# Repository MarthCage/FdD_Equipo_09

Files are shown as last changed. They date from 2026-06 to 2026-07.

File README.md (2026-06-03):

> Activar modo oscuro, por favor...

# Typing SVG (https://git.io/typing-svg)

<!-- # Equipo 09 ★ Fundamentos de Diseño ⋆｡°✩ -->
### Carrera de Ingeniería Ambiental / Informática / Industrial  
**Universidad Peruana Cayetano Heredia**

---

### <code> Descripción del Equipo ── .✦🌍 </code> 
Somos el **Equipo 09** del curso **Fundamentos de Diseño 2026-1**, conformado por estudiantes de las carreras de Ingeniería Ambiental, Informática e Industrial. Nuestro objetivo es aplicar la metodología de diseño para generar soluciones innovadoras con impacto social, tecnológico y ambiental. Somos piolas :]

---

### <code> Integrantes del Equipo ── .✦👥 </code>

<table align="center">
  <tr height="150">
    <td valign="center" width="200" align="center">
      
    </td>
    <td valign="middle">
      <b>Martha Medina˖.𖥔 ݁ ˖ ⊹ ࣪ ˖</b><br>
      Líder, documentadora y programadora<br>
      Gustos: Programación, creatividad
    </td>
    <td valign="center" width="200" align="center">
      
    </td>
    <td valign="middle">
      <b>Aldair Castillo˖.𖥔 ݁ ˖ ⊹ ࣪ ˖</b><br>
      Programador, documentador<br>
      Gustos: Ciencias de la computación, Mecatrónica
    </td>
  </tr>
  <tr height="150">
    <td valign="center" width="200" align="center">
      
    </td>
    <td valign="middle">
      <b>Anderson Bruno˖.𖥔 ݁ ˖ ⊹ ࣪ ˖</b><br>
      Documentador<br>
      Gustos: Diseño de prototipos, creatividad, análisis
    </td>
    <td valign="center" width="200" align="center">
      
    </td>
    <td valign="middle">
      <b>Angel Valverde˖.𖥔 ݁ ˖ ⊹ ࣪ ˖</b><br>
      Evaluador ambiental, documentador<br>
      Gustos: Comunicador , Asertivo , Colaborativo
    </td>
  </tr>
  <tr height="150">
    <td valign="center" width="200" align="center">
      
    </td>
    <td valign="middle">
      <b>Xiomara Quispe˖.𖥔 ݁ ˖ ⊹ ࣪ ˖</b><br>
      Documentadora<br>
      Gustos: Optimización de procesos, análisis de datos
    </td>
  </tr>
</table>

---

### <code> Fotografía del Equipo ── .✦📸 </code>

<p align="center">
imagen_alumnos_IA
  <em>Figura 1. Fotografía del equipo 09</em>
</p>

---

### <code> ODS elegida ── .✦🌍 </code> 
En este presente proyecto de innovación, se abordar una problemática vinculada al Objetivo de Desarrollo Sostenible 15 (ODS15): Vida de Ecosistema Terrestre, propuesto en la Agenda 2030. Este objetivo comprende un conjunto amplio de metas interrelacionadas que reflejan un enfoque integral orientado a la conservación de los ecosistemas terrestres y de la biodiversidad, promoviendo  soluciones que contribuyan a reducir el impacto de las actividad humana y la fauna silvestre sin alterar el equilibrio ecológico (1).

A partir de esta perspectiva, nuestro proyecto se centrará en la prevención de la pérdida de bosques ocasionada por la tala ilegal.

---

### <code> Problemática ── .✦‼️ </code> 
La deforestación se ha convertido en una de las amenazas ambientales más críticas a nivel mundial, especialmente en regiones tropicales como la Amazonía. Según reportes internacionales, más del 94% de la deforestación global ocurre en los trópicos, donde se concentran los ecosistemas más biodiversos del planeta (2).

<p align = "center">
  Captura de pantalla 2026-04-13 212824
  <br>
  <em>Tala ilegal en la Amazonía peruana (Madre de Dios).
 Nota. Tomado de Isolated Tribes and Forests Threatened by New Amazon Road, por N. Drake, 2018, National Geographic. (4)
</em>
</p>

En este contexto, el Perú no es ajeno a esta problemática. Datos de plataformas como Global Forest Watch muestran que la pérdida de cobertura arbórea en el país ha sido constante desde el año 2001, debido principalmente a actividades humanas como la agricultura, la tala y la expansión de infraestructura. Incluso, en los últimos años se han registrado incrementos significativos en la pérdida de bosques, reflejando una tendencia preocupante que continúa en aumento. Por ejemplo, en el año 2022 se registró la pérdida de aproximadamente 160 mil hectáreas de cobertura arbórea en el Perú, posicionando al país en el quinto lugar entre las naciones con mayor pérdida de bosque primario a nivel mundial con más bajas de bosque primario a nivel mundial, evidenciando así la magnitud actual del problema. Asimismo, se estima que el 67% de la pérdida de cobertura arbórea en el país está directamente asociada a procesos de deforestación, principalmente por actividades humanas como la agricultura y la tala  (2)(3).

<p align = "center">
  
  <br>
  <em>Imagen 2. Pérdida de cobertura arbórea en Perú (2001–2024). Fuente: Global Forest Watch (2024).  (3)
</em>
</p>

La importancia de esta problemática radica en sus consecuencias directas sobre el clima. La deforestación contribuye de manera significativa a las emisiones de gases de efecto invernadero, ya que los bosques almacenan grandes cantidades de carbono. Cuando estos son talados o quemados, ese carbono se libera en forma de CO₂, intensificando el calentamiento global (4). A nivel global, la pérdida de bosques tropicales está directamente relacionada con el incremento de la temperatura del planeta y eventos climáticos extremos.
Además, la Amazonía peruana alberga una enorme diversidad biológica, considerada una de las más altas del mundo. Sin embargo, la pérdida de hábitats está provocando la disminución de especies y alteraciones en los ecosistemas. La destrucción de estos ambientes también incrementa el riesgo de enfermedades zoonóticas, ya que el contacto entre humanos y animales silvestres se vuelve más frecuente (1)(4).
A nivel nacional, el problema se agrava por la ilegalidad. En el Perú, se han detectado más de 24 mil metros cúbicos de madera de origen ilegal, así como cargamentos valorizados en millones de soles, lo que evidencia la magnitud económica y ambiental de esta actividad. Un caso representativo es el ocurrido en Ucayali, donde se intervino madera ilegal valorizada en más de seis millones de soles, reflejando la alta rentabilidad de esta práctica y su impacto directo en la deforestación del país  (6)(7). Esto demuestra que la deforestación no solo es un problema ecológico, sino también social y económico.
Asimismo, la alta demanda comercial de determinadas especies forestales incrementa la presión sobre los bosques amazónicos. Entre las maderas más valoradas se encuentran la caoba (Swietenia macrophylla) y el cedro (Cedrela odorata), ampliamente utilizadas en la fabricación de muebles, acabados y productos de exportación. Debido a su elevado valor económico, estas especies han sido históricamente objeto de sobreexplotación y extracción ilegal, contribuyendo significativamente a la pérdida de cobertura forestal y al deterioro de los ecosistemas amazónicos (9).

<p align = "center">
imagen
<br>
  <em>imagen 3. Intervención de madera ilegal valorizada en más de seis millones de soles en Ucayali. Fuente: Ministerio del Interior del Perú. Ucayali: intervienen madera valorizada en más de seis millones de soles, 2023. (6)</em>
</p>

Asimismo, el modelo de desarrollo basado en la explotación de recursos ha generado una presión constante sobre los bosques amazónicos. En muchos casos, el crecimiento económico ha sido priorizado sobre la sostenibilidad, lo que ha llevado a la degradación progresiva de los ecosistemas y la pérdida de servicios ambientales esenciales como la regulación del clima y el ciclo del agua (5).
Desde una perspectiva científica, la deforestación altera procesos fundamentales como el ciclo del carbono y el equilibrio de los ecosistemas, afectando tanto a la naturaleza como a las poblaciones humanas que dependen de estos recursos para su subsistencia (8).

---

### <code> Solución ── .✦🌟 </code> 
En respuesta a la necesidad de una solución no invasiva y tras analizar la magnitud de la problemática, se propone el desarrollo de un dispositivo tecnológico innovador diseñado para detectar posibles actividades de tala ilegal en zonas vulnerables de la Amazonía. Este sistema funcionará como un mecanismo de monitoreo inteligente que integrará un micrófono para captar los sonidos del entorno y, mediante el análisis de espectros de frecuencia y técnicas de inteligencia artificial, diferenciar sonidos asociados a motosierras, maquinaria pesada, voces humanas y otros eventos relevantes.

Asimismo, el dispositivo estará basado en un microcontrolador ESP32-S3 e integrará sensores de presencia, vibración e inclinación, además de un módulo GPS para la geolocalización de eventos. Gracias a su bajo consumo energético y a la integración con una aplicación móvil, los usuarios podrán visualizar alertas, ubicación aproximada y nivel de riesgo en tiempo real. De esta manera, se busca ofrecer una solución eficiente, accesible y sostenible que contribuya a la detección temprana de actividades de tala ilegal, fortaleciendo la vigilancia forestal y apoyando la conservación de los ecosistemas amazónicos.

### <code> Objetivos ── .✦✅ </code>

- Diseñar un sistema basado en ESP32-S3 para detectar posibles casos de tala ilegal.
- Implementar un micrófono para identificar sonidos de motosierras, maquinaria y voces humanas.
- Integrar sensores de presencia y vibración para mejorar la precisión de detección.
- Enviar alertas con ubicación GPS a una aplicación móvil en tiempo real.
- Contribuir a la vigilancia y conservación de los bosques en el marco del ODS 15.

---

### <code> Patentes encontradas ── .✦📃 </code>
<!--- Patente 1 ------------------------------------------------------------------------------------------------->
<table>
  <tr>
    <th>TÍTULO</th>
    <td colspan="2"><b>SISTEMA DE DETECCIÓN DE EVENTOS SONOROS ACÚSTICOS</b></td>
  </tr>

  <tr>
    <th>NÚMERO DE PUBLICACIÓN</th>
    <td>US2025046333A1</td>
    <th>IMAGEN</th>
  </tr>

  <tr>
    <th>RESUMEN</th>
    <td>
      Esta patente describe un sistema de Machine Learning diseñado exclusivamente para clasificar "sonidos no verbales" (ruidos mecánicos, impactos, motores) extrayendo "embeddings" (vectores de características). El sistema puede aprender a reconocer una nueva clase de sonido (como un modelo específico de motosierra) usando muy pocos ejemplos de audio, sin confundirse con sonidos biológicos.
    </td>
    <td align="center">
      <br><br>
      
  </tr>

  <tr>
    <th>LINK</th>
    <td colspan="2">
      <a href="https://worldwide.espacenet.com/patent/search/family/087348851/publication/US2025046333A1?q=US20250046333A1">
        Ver patente
      </a>
    </td>
  </tr>
</table>

<br><br>

<!--- Patente 2 -------------------------------------------------------------------------------------------------->
<table>
  <tr>
    <th>TÍTULO</th>
    <td colspan="2"><b>
      Detección de tipo de audio.
    </b></td>
  </tr>

  <tr>
    <th>NÚMERO DE PUBLICACIÓN</th>
    <td>US10978050B2</td>
    <th>IMAGEN</th>
  </tr>

  <tr>
    <th>RESUMEN</th>
    <td>
      El procesamiento basado en inteligencia artificial puede utilizarse para clasificar la información de audio recibida de una unidad de entrada de audio. Por ejemplo, se puede recibir información de audio de un micrófono configurado para monitorizar un entorno. Un circuito procesador puede identificar una o más características de la información de audio recibida del micrófono y utilizar un primer algoritmo de aprendizaje automático para analizar dichas características y determinar si la información de audio incluye algún indicio de un evento anómalo en el entorno. En otro ejemplo, el circuito procesador puede utilizar un segundo algoritmo de aprendizaje automático diferente, como un algoritmo de aprendizaje profundo basado en redes neuronales, para analizar las mismas características y clasificar la información de audio como indicativa de un tipo de evento específico en el entorno 
.
    </td>
    <td align="center">
      
      <br><br>

  </tr>

  <tr>
    <th>LINK</th>
    <td colspan="2">
      <a href="https://worldwide.espacenet.com/patent/search/family/067618015/publication/US2025104698A1?q=US10978050B22">
        Ver patente
      </a>
    </td>
  </tr>
</table>

<br><br>

<!--- Patente 3 -------------------------------------------------------------------------------------------------->
<table>
  <tr>
    <th>TÍTULO</th>
    <td colspan="2"><b>
       Método, dispositivo y sistema de detección de tala ilegal basado en la diferenciación de frecuencias de audio.
    </b></td>
  </tr>

  <tr>
    <th>NÚMERO DE PUBLICACIÓN</th>
    <td>CN102393986A</td>
    <th>IMAGEN</th>
  </tr>

  <tr>
    <th>RESUMEN</th>
    <td>
 La invención proporciona un método, un dispositivo y un sistema para la detección de tala ilegal basados en la diferenciación de frecuencias de audio. Este método permite identificar actividades de tala ilegal en cualquier momento mediante la simple recolección de sonidos del entorno, presentando una baja complejidad técnica, así como costos reducidos de desarrollo y uso, además de una alta eficiencia en la detección y ejecución.
En consecuencia, el dispositivo de detección que emplea este método se caracteriza por su bajo costo de desarrollo, corto tiempo de implementación y alta eficiencia, lo que lo hace adecuado para su producción y desarrollo a nivel industrial. Asimismo, mediante la integración de este dispositivo con funciones de comunicación inalámbrica, se construye un sistema de detección de tala ilegal que permite el monitoreo remoto, la identificación de la ubicación donde ocurre la actividad ilícita y la aplicación de medidas específicas para prevenirla.
Este método, dispositivo y sistema basados en la diferenciación de frecuencias de audio logran resolver problemas presentes en tecnologías anteriores, como la dificultad en la detección de la tala ilegal y sus altos costos, mostrando además un amplio potencial de aplicación
    </td>
    <td align="center">
      
      <br><br>
      
    </td>
  </tr>

  <tr>
    <th>LINK</th>
    <td colspan="2">
      <a href="https://worldwide.espacenet.com/patent/search/family/045861294/publication/CN102393986A">
        Ver patente
      </a>
    </td>
  </tr>
</table>

<br><br>

<!--- Patente 4 -------------------------------------------------------------------------------------------------->
<table>
  <tr>
    <th>TÍTULO</th>
    <td colspan="2"><b>
        Sistema dinámico de firmas acústicas con fusión de sensores para la tala ilegal en la selva tropical
    </b></td>
  </tr>

  <tr>
    <th>NÚMERO DE PUBLICACIÓN</th>
    <td>US20240054154A1</td>
    <th>IMAGEN</th>
  </tr>

  <tr>
    <th>RESUMEN</th>
    <td>
 Las implementaciones de ejemplo descritas en este documento pueden estar dirigidas a detectar una perturbación humana a partir de datos de sensores transmitidos desde uno o más sensores dentro de una red de sensores; procesar la perturbación humana detectada para determinar una probabilidad de un evento de motosierra —por ejemplo, un evento de motosierra leve o intenso— y un tiempo estimado de anticipación para dicho evento de motosierra en un área asociada con uno o más sensores; y determinar, para los sensores vecinos de esos sensores dentro de la red, una probabilidad de cambio de estado hacia la perturbación humana o hacia el evento de motosierra en otras áreas asociadas con los sensores vecinos.
    </td>
    <td align="center">
      
      <br><br>
      
    </td>
  </tr>

  <tr>
    <th>LINK</th>
    <td colspan="2">
      <a href="https://worldwide.espacenet.com/patent/search/family/082259630/publication/US2024054154A1?q=US20240054154A1">
        Ver patente
      </a>
    </td>
  </tr>
</table>

<br><br>

---

### <code> Bibliografías ── .✦📚 </code> 
BIBLIOGRAFÍAS:
1. Moran M. ODS15: Bosques, desertificación y diversidad biológica [Internet]. Desarrollo Sostenible. 26 de enero de 2024 [citado el 14 de abril de 2026]. Disponible en: https://www.un.org/sustainabledevelopment/es/biodiversity/
2. Weisse M, Goldman E, Carter S. ¿Cuánto bosque se perdió en 2022? [Internet]. Global Forest Review; 2023 [citado 19 de abril de 2026]. Disponible en: https://gfr.wri.org/es/global-tree-cover-loss-data-2022  
3. Global Forest Watch. Peru Deforestation Rates & Statistics [Internet]. Washington, D.C.: Global Forest Watch; s. f. [citado 19 de abril de 2026]. Disponible en: https://www.globalforestwatch.org/dashboards/country/PER/ 
4. Nunez C. Why deforestation matters—and what we can do to stop it [Internet]. National Geographic; 2025 [citado 19 de abril de 2026]. Disponible en: https://www.nationalgeographic.com/environment/article/deforestation
5. Quispe Alí KE. Deforestación en la Amazonía: el costo ambiental de un desarrollo sin control [Internet]. Lima: Pontificia Universidad Católica del Perú, Clima de Cambios; 2025 [citado 19 de abril de 2026]. Disponible en: https://www.pucp.edu.pe/climadecambios/noticias/deforestacion-en-la-amazonia-el-costo-ambiental-de-un-desarrollo-sin-control/ 
6. Organismo de Supervisión de los Recursos Forestales y de Fauna Silvestre. OSINFOR identificó más de 24 mil metros cúbicos de madera de origen ilegal mediante inteligencia artificial en el monitoreo satelital [Internet]. Lima: OSINFOR; 2025 [citado 19 de abril de 2026]. Disponible en: https://www.gob.pe/institucion/osinfor/noticias/1191654-osinfor-identifico-mas-de-24-mil-metros-cubicos-de-madera-de-origen-ilegal-mediante-inteligencia-artificial-e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  
7. Ministerio del Interior. Ucayali: Intervienen madera valorizada en más de seis millones de soles [Internet]. Lima: Ministerio del Interior; 2023 [citado 19 de abril de 2026]. Disponible en: https://www.gob.pe/institucion/mininter/noticias/828157-ucayali-intervienen-madera-valorizada-en-mas-de-seis-millones-de-soles
8. La Barreda Noa SD. Deforestación en la región amazónica del Perú: situación y perspectivas. M+Rev Electrón Medioambiente [Internet]. 2021 [citado el 27 de abril de 2026];22(2):20–39. Disponible en: https://dialnet.unirioja.es/servlet/articulo?codigo=8488495 
9. Servicio Nacional Forestal y de Fauna Silvestre (SERFOR). SERFOR decomisa cargamento de caoba y cedro valorizado en 80 mil soles, Lima: SERFOR; 2024 [citado 2026 Jun 3]. Disponible en: https://www.gob.pe/institucion/serfor/noticias/1053504-serfor-decomisa-cargamento-de-caoba-y-cedro-valorizado-en-80-mil-soles

## 📌 Resumen Final  
> El proyecto aborda el impacto la tala ilegal en el Amazonas, ya que la pérdida de bosques implica un peligro para el ambiente. Como solución, se propone un dispositivo con inteligencia artificial que detecte y alarme una posible actividad de este tipo y sin dañar los alrededores, promoviendo así una solución sostenible y equilibrada con el ecosistema.

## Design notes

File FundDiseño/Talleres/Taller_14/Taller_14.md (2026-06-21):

# ACTIVIDAD 1:

No se pudo completar

# ACTIVIDAD 2: Control de ángulo de un servomotor con ESP32 mediante Bluetooth

## 1. Descripción general

En esta actividad se desarrolló un sistema para controlar el ángulo de giro de un servomotor utilizando un ESP32 y una aplicación móvil creada en MIT App Inventor.

La comunicación entre la aplicación y el ESP32 se realiza mediante Bluetooth clásico. Desde la aplicación, el usuario mueve un control deslizante o *slider*, el cual envía un valor numérico al ESP32. Luego, el ESP32 recibe ese valor, lo procesa y mueve el servomotor al ángulo correspondiente.

El sistema permite controlar el servomotor de manera inalámbrica, usando un teléfono Android como interfaz de control.

---

## 2. Código utilizado en el ESP32

```cpp
#include "BluetoothSerial.h"
#include <ESP32Servo.h>

BluetoothSerial SerialBT;
Servo servoMotor;

int pinServo = 13;
int angulo = 0;

void setup() {
  Serial.begin(115200);

  SerialBT.begin("ESP32_SERV0");
  Serial.println("Bluetooth iniciado como ESP32_SERVO");

  servoMotor.attach(pinServo);
  servoMotor.write(0);

  Serial.println("Servo listo");
}

void loop() {
  if (SerialBT.available()) {
    String dato = SerialBT.readStringUntil('\n');
    dato.trim();

    if (dato.length() > 0) {
      angulo = dato.toInt();

      if (angulo < 0) {
        angulo = 0;
      }

      if (angulo > 270) {
        angulo = 270;
      }

      int anguloServo = map(angulo, 0, 270, 0, 180);

      servoMotor.write(anguloServo);

      Serial.print("Ángulo recibido: ");
      Serial.println(angulo);
    }
  }
}
```

---

## 3. Explicación del código

### 3.1 Librerías utilizadas

Al inicio del programa se incluyen dos librerías:

```cpp
#include "BluetoothSerial.h"
#include <ESP32Servo.h>
```

La librería `BluetoothSerial.h` permite usar la comunicación Bluetooth clásica del ESP32. Gracias a esta librería, el ESP32 puede recibir datos enviados desde la aplicación móvil.

La librería `ESP32Servo.h` permite controlar el servomotor conectado al ESP32. Esta librería es necesaria porque el manejo de servomotores en ESP32 requiere una configuración diferente a la utilizada en placas como Arduino UNO.

---

### 3.2 Creación de objetos

Después se crean dos objetos principales:

```cpp
BluetoothSerial SerialBT;
Servo servoMotor;
```

El objeto `SerialBT` se utiliza para manejar la comunicación Bluetooth entre el celular y el ESP32.

El objeto `servoMotor` representa al servomotor que será controlado desde el programa.

---

### 3.3 Declaración de variables

Luego se declaran las variables principales del sistema:

```cpp
int pinServo = 13;
int angulo = 0;
```

La variable `pinServo` indica que el cable de señal del servomotor está conectado al pin GPIO 13 del ESP32.

La variable `angulo` almacena el valor recibido desde la aplicación móvil. Este valor corresponde a la posición seleccionada en el slider.

---

### 3.4 Configuración inicial del programa

La función `setup()` se ejecuta una sola vez al iniciar el ESP32. En esta parte se configuran la comunicación serial, el Bluetooth y el servomotor.

Primero se inicia la comunicación serial:

```cpp
Serial.begin(115200);
```

Esta instrucción permite mostrar mensajes en el monitor serial del Arduino IDE. Sirve para verificar si el ESP32 está funcionando correctamente y si recibe los datos enviados por Bluetooth.

Luego se inicia el Bluetooth del ESP32 con el nombre `ESP32_SERVO`:

```cpp
SerialBT.begin("ESP32_SERVO");
Serial.println("Bluetooth iniciado como ESP32_SERVO");
```

Este nombre será visible desde el celular al momento de buscar dispositivos Bluetooth. Por ello, en la aplicación móvil se debe seleccionar el dispositivo llamado `ESP32_SERVO`.

Después se configura el pin del servomotor:

```cpp
servoMotor.attach(pinServo);
servoMotor.write(0);
```

La instrucción `servoMotor.attach(pinServo)` indica que el servomotor será controlado desde el pin GPIO 13.

La instrucción `servoMotor.write(0)` coloca inicialmente el servomotor en la posición 0.

Finalmente, se muestra un mensaje indicando que el servo ya está listo:

```cpp
Serial.println("Servo listo");
```

---

### 3.5 Lectura de datos por Bluetooth

La función `loop()` se ejecuta de manera repetitiva mientras el ESP32 está encendido. Dentro de esta función se verifica constantemente si llegó algún dato por Bluetooth:

```cpp
if (SerialBT.available()) {
```

La instrucción `SerialBT.available()` comprueba si existe información disponible para leer. Si la aplicación móvil envía un valor desde el slider, esta condición se cumple.

Cuando hay información disponible, el programa lee el dato recibido:

```cpp
String dato = SerialBT.readStringUntil('\n');
dato.trim();
```

La instrucción `readStringUntil('\n')` lee el texto recibido hasta encontrar un salto de línea. Este salto de línea es enviado desde MIT App Inventor junto con el valor del slider.

La instrucción `dato.trim()` elimina espacios o caracteres innecesarios al inicio y al final del dato recibido. Esto ayuda a evitar errores al convertir el texto en número.

---

### 3.6 Validación del dato recibido

Antes de usar el dato, se verifica que no esté vacío:

```cpp
if (dato.length() > 0) {
```

Esta condición evita que el programa intente procesar un dato vacío. Si el dato tiene contenido, se convierte de texto a número entero:

```cpp
angulo = dato.toInt();
```

Esto es necesario porque los datos enviados por Bluetooth llegan como texto. Para controlar el servomotor, el valor debe convertirse a un número entero.

Por ejemplo, si la aplicación envía el texto `"90"`, el ESP32 lo convierte al número `90`.

---

### 3.7 Límite del ángulo permitido

Luego, el programa verifica que el ángulo recibido esté dentro del rango permitido:

```cpp
if (angulo < 0) {
  angulo = 0;
}

if (angulo > 270) {
  angulo = 270;
}
```

Estas condiciones evitan que el valor del ángulo sea menor que 0 o mayor que 270.

Si el valor recibido es menor que 0, el programa lo corrige a 0.

Si el valor recibido es mayor que 270, el programa lo corrige a 270.

Esto permite proteger el funcionamiento del sistema y mantener el movimiento dentro del rango definido para la actividad.

---

### 3.8 Conversión del rango del slider al rango del servo

El slider de la aplicación trabaja con valores de 0 a 270. Sin embargo, la función `servoMotor.write()` normalmente trabaja con valores de 0 a 180.

Por esa razón, se utiliza la función `map()`:

```cpp
int anguloServo = map(angulo, 0, 270, 0, 180);
```

Esta instrucción convierte proporcionalmente el valor recibido desde la aplicación.

Ejemplos:

| Valor enviado por la app | Valor usado por el servo |
|---|---|
| 0 | 0 |
| 135 | 90 |
| 270 | 180 |

De esta manera, el valor del slider se adapta al rango que puede interpretar correctamente la librería del servomotor.

---

### 3.9 Movimiento del servomotor

Después de convertir el valor, el servomotor se mueve al ángulo calculado:

```cpp
servoMotor.write(anguloServo);
```

Esta instrucción envía la señal al servomotor para que gire a la posición correspondiente.

Por ejemplo, si desde la aplicación se envía el valor 135, el programa lo convierte aproximadamente a 90, y el servomotor se mueve a esa posición.

---

### 3.10 Visualización en el monitor serial

Finalmente, el programa muestra el valor recibido en el monitor serial:

```cpp
Serial.print("Ángulo recibido: ");
Serial.println(angulo);
```

Esto permite comprobar que el ESP32 está recibiendo correctamente los datos desde la aplicación móvil.

Por ejemplo, si el usuario mueve el slider a 90, en el monitor serial se mostrará:

```text
Ángulo recibido: 90
```

Esta parte es útil para realizar pruebas y verificar que la comunicación Bluetooth funciona correctamente.

---

## 4. Funcionamiento general del sistema

El funcionamiento general del sistema es el siguiente:

1. El usuario abre la aplicación móvil creada en MIT App Inventor.
2. La aplicación se conecta al ESP32 mediante Bluetooth.
3. El usuario mueve el slider para seleccionar un ángulo.
4. La aplicación envía el valor del slider al ESP32.
5. El ESP32 recibe el dato por Bluetooth.
6. El programa convierte el dato recibido en un número entero.
7. El valor se limita entre 0 y 270.
8. El valor se convierte al rango de 0 a 180.
9. El servomotor gira a la posición correspondiente.

---

## 5. Conexión del servomotor

La conexión utilizada para el servomotor fue la siguiente:

| Cable del servomotor | Conexión en el ESP32 |
|---|---|
| Rojo | 5V |
| Marrón o negro | GND |
| Naranja o amarillo | GPIO 13 |

El cable rojo alimenta el servomotor, el cable marrón o negro se conecta a tierra y el cable naranja o amarillo recibe la señal de control desde el ESP32.

## 6. Diseño de app en MIT App Inventor:
imagen

## 7. Programación por bloques:

En esta sección se explican los bloques utilizados en MIT App Inventor para controlar el servomotor mediante Bluetooth. La aplicación permite conectarse al ESP32, enviar el valor del slider y actualizar el estado de conexión en pantalla.

Los bloques principales utilizados son:

- `Screen1.Initialize`
- `btn_connect.BeforePicking`
- `btn_connect.AfterPicking`
- `slider.PositionChanged`
- `Clock1.Timer`

--- 

imagen
imagen

---

### 7.1 Bloque `Screen1.Initialize`

El bloque `Screen1.Initialize` se ejecuta automáticamente cuando se abre la aplicación.

```text
when Screen1.Initialize
do
    set lbl_estado.Text to "Estado: Sin conectar"
    set lbl_angulo.Text to "0"
    set slider.MinValue to 0
    set slider.MaxValue to 270
    set slider.ThumbPosition to 0
```

Este bloque se encarga de establecer los valores iniciales de la aplicación.

Primero, la etiqueta `lbl_estado` muestra el mensaje:

```text
Estado: Sin conectar
```

Esto indica que al iniciar la aplicación todavía no existe conexión Bluetooth con el ESP32.

Luego, la etiqueta `lbl_angulo` muestra el valor inicial:

```text
0
```

Este valor representa la posición inicial del slider.

Después, se configura el rango del slider. El valor mínimo se establece en `0` y el valor máximo en `270`. Esto permite que el usuario seleccione un valor dentro del rango definido para la actividad.

Finalmente, la posición inicial del slider se coloca en `0`, para que al abrir la aplicación el control empiece desde el valor mínimo.

---

### 7.2 Bloque `btn_connect.BeforePicking`

El bloque `btn_connect.BeforePicking` se ejecuta antes de que el usuario seleccione un dispositivo Bluetooth.

```text
when btn_connect.BeforePicking
do
    set btn_connect.Elements to BluetoothClient1.AddressesAndNames
```

Este bloque carga en el botón de conexión la lista de dispositivos Bluetooth disponibles o previamente emparejados con el celular.

La propiedad `BluetoothClient1.AddressesAndNames` obtiene los nombres y direcciones de los dispositivos Bluetooth. Luego, esa información se asigna a los elementos del botón `btn_connect`.

Gracias a este bloque, cuando el usuario presiona el botón de conexión, la aplicación muestra una lista de dispositivos Bluetooth disponibles para conectarse.

En esta actividad, el dispositivo que debe seleccionarse es:

```text
ESP32_SERVO
```

Ese es el nombre asignado al ESP32 dentro del código cargado en Arduino IDE.

---

### 7.3 Bloque `btn_connect.AfterPicking`

El bloque `btn_connect.AfterPicking` se ejecuta después de que el usuario selecciona un dispositivo Bluetooth de la lista.

```text
when btn_connect.AfterPicking
do
    if BluetoothClient1.Connect address btn_connect.Selection
    then
        set lbl_estado.Text to "Estado: Conectado"
    else
        set lbl_estado.Text to "Estado: Error D:"
```

Este bloque intenta conectar la aplicación con el dispositivo Bluetooth seleccionado.

La instrucción:

```text
BluetoothClient1.Connect address btn_connect.Selection
```

usa el dispositivo elegido por el usuario en `btn_connect`. Si la conexión se realiza correctamente, la etiqueta `lbl_estado` cambia a:

```text
Estado: Conectado
```

Esto indica que el celular ya se encuentra conectado al ESP32.

Si la conexión falla, la aplicación muestra:

```text
Estado: Error D:
```

Este mensaje indica que no se pudo establecer la conexión Bluetooth. Esto puede suceder si el ESP32 está apagado, si no fue emparejado previamente con el celular o si se seleccionó un dispositivo incorrecto.

---

### 7.4 Bloque `slider.PositionChanged`

El bloque `slider.PositionChanged` se ejecuta cada vez que el usuario mueve el slider.

```text
when slider.PositionChanged thumbPosition
do
    set lbl_angulo.Text to round slider.ThumbPosition

    if BluetoothClient1.IsConnected
    then
        call BluetoothClient1.SendText
            text join round slider.ThumbPosition "\n"
```

Este bloque tiene dos funciones principales. La primera es mostrar en pantalla el valor actual del slider. La segunda es enviar ese valor al ESP32 mediante Bluetooth.

Primero, se actualiza la etiqueta `lbl_angulo`:

```text
set lbl_angulo.Text to round slider.ThumbPosition
```

La función `round` redondea el valor del slider para que se muestre como un número entero. Esto evita que aparezcan valores decimales en la pantalla.

Por ejemplo, si el usuario mueve el slider hacia el valor 90, la etiqueta mostrará:

```text
90
```

Luego, el bloque verifica si existe conexión Bluetooth:

```text
if BluetoothClient1.IsConnected
```

Esta condición es importante porque la aplicación solo debe enviar datos cuando está conectada al ESP32.

Si la conexión está activa, se envía el valor del slider usando:

```text
BluetoothClient1.SendText
```

El dato enviado está formado por el valor redondeado del slider unido con un salto de línea:

```text
join round slider.ThumbPosition "\n"
```

El salto de línea `\n` sirve para indicar el final del dato enviado. Esto permite que el ESP32 lea correctamente la información usando la instrucción:

```cpp
readStringUntil('\n')
```

Por ejemplo, si el usuario mueve el slider al valor 90, la aplicación envía:

```text
90\n
```

El ESP32 recibe ese dato, lo convierte a número entero y mueve el servomotor según el valor recibido.

---

### 7.5 Bloque `Clock1.Timer`

El bloque `Clock1.Timer` se ejecuta de manera repetitiva cada cierto intervalo de tiempo.

```text
when Clock1.Timer
do
    if BluetoothClient1.IsConnected
    then
        set lbl_estado.Text to "Estado: Conectado"
    else
        set lbl_estado.Text to "Estado: Sin conectar"
        set btn_connect.Text to "Conectar"
```

Este bloque sirve para verificar constantemente si la aplicación sigue conectada al ESP32.

Primero, se revisa el estado de la conexión Bluetooth mediante:

```text
BluetoothClient1.IsConnected
```

Si la conexión continúa activa, la etiqueta `lbl_estado` muestra:

```text
Estado: Conectado
```

Esto permite que el usuario sepa que la comunicación con el ESP32 sigue funcionando.

Si la conexión se pierde o todavía no se ha conectado ningún dispositivo, la etiqueta cambia a:

```text
Estado: Sin conectar
```

Además, el texto del botón vuelve a mostrarse como:

```text
Conectar
```

Esto permite que el usuario pueda intentar conectarse nuevamente.

El uso del componente `Clock1` es útil porque mantiene actualizada la interfaz de la aplicación y permite supervisar el estado de la conexión Bluetooth.

---

### 7.6 Funcionamiento general de los bloques

El funcionamiento de los bloques de la aplicación sigue el siguiente proceso:

1. Al abrir la aplicación, el bloque `Screen1.Initialize` configura los valores iniciales.
2. La aplicación muestra el estado inicial como `Estado: Sin conectar`.
3. El slider se configura con un valor mínimo de `0`, un valor máximo de `270` y una posición inicial de `0`.
4. Cuando el usuario presiona el botón de conexión, el bloque `btn_connect.BeforePicking` carga la lista de dispositivos Bluetooth disponibles.
5. El usuario selecciona el dispositivo `ESP32_SERVO`.
6. El bloque `btn_connect.AfterPicking` intenta establecer la conexión Bluetooth con el ESP32.
7. Si la conexión es correcta, la aplicación muestra `Estado: Conectado`.
8. Cuando el usuario mueve el slider, el bloque `slider.PositionChanged` muestra el valor seleccionado en la etiqueta `lbl_angulo`.
9. Si la aplicación está conectada, el valor del slider se envía al ESP32 mediante Bluetooth.
10. El bloque `Clock1.Timer` verifica constantemente si la conexión sigue activa.

---

### 7.7 Relación entre la aplicación y el ESP32

La aplicación móvil y el ESP32 trabajan juntos mediante comunicación Bluetooth.

La aplicación envía valores numéricos desde el slider. Estos valores representan el ángulo seleccionado por el usuario. El ESP32 recibe esos valores como texto, los convierte a número entero y los utiliza para mover el servomotor.

Por ejemplo:

| Acción en la aplicación | Dato enviado al ESP32 | Resultado esperado |
|---|---|---|
| Slider en 0 | `0\n` | El servo se mantiene en la posición inicial |
| Slider en 90 | `90\n` | El servo gira a una posición intermedia |
| Slider en 180 | `180\n` | El servo gira hacia una posición mayor |
| Slider en 270 | `270\n` | El servo llega al valor máximo configurado |

El salto de línea `\n` permite que el ESP32 identifique correctamente el final de cada dato recibido.

---

### 7.8 Importancia del componente `BluetoothClient`

El componente `BluetoothClient1` es el encargado de realizar la comunicación Bluetooth entre la aplicación y el ESP32.

En este proyecto, sus funciones principales son:

- Mostrar los dispositivos Bluetooth disponibles.
- Conectarse al ESP32 seleccionado.
- Verificar si la conexión está activa.
- Enviar el valor del slider al ESP32.

Sin este componente, la aplicación no podría comunicarse de forma inalámbrica con el ESP32.

---

### 7.9 Importancia del componente `Clock1`

El componente `Clock1` permite ejecutar acciones de manera repetitiva cada cierto tiempo.

En esta aplicación se utiliza para verificar si el Bluetooth sigue conectado. Gracias a esto, la aplicación puede actualizar automáticamente el mensaje de estado en la pantalla.

Esto mejora la experiencia del usuario, ya que permite saber si la aplicación está conectada o desconectada del ESP32.

---

## 7.10 Conclusión de los bloques de la aplicación

Los bloques desarrollados en MIT App Inventor permiten que la aplicación móvil funcione como una interfaz de control para el servomotor. Al iniciar la aplicación, se configuran los valores principales; luego, el usuario puede conectarse al ESP32 mediante Bluetooth y enviar el valor del slider.

El componente `BluetoothClient1` permite establecer la comunicación inalámbrica, mientras que el componente `Clock1` permite supervisar el estado de conexión. En conjunto, estos bloques permiten controlar el movimiento del servomotor desde el celular de forma sencilla y en tiempo real.

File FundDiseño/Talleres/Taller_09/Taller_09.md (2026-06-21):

# Taller 09

## Diagrama de flujo:



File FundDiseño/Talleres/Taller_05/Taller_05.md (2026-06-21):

#Pitch

En este taller se elaboró el pitch y la presentación mediante un canva

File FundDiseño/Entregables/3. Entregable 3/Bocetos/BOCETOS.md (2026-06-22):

# YURA GUARD - Bocetos

## Descripción

Bocetos del diseño del dispositivo YURA GUARD.

---

## Boceto 1: Vista Isométrica

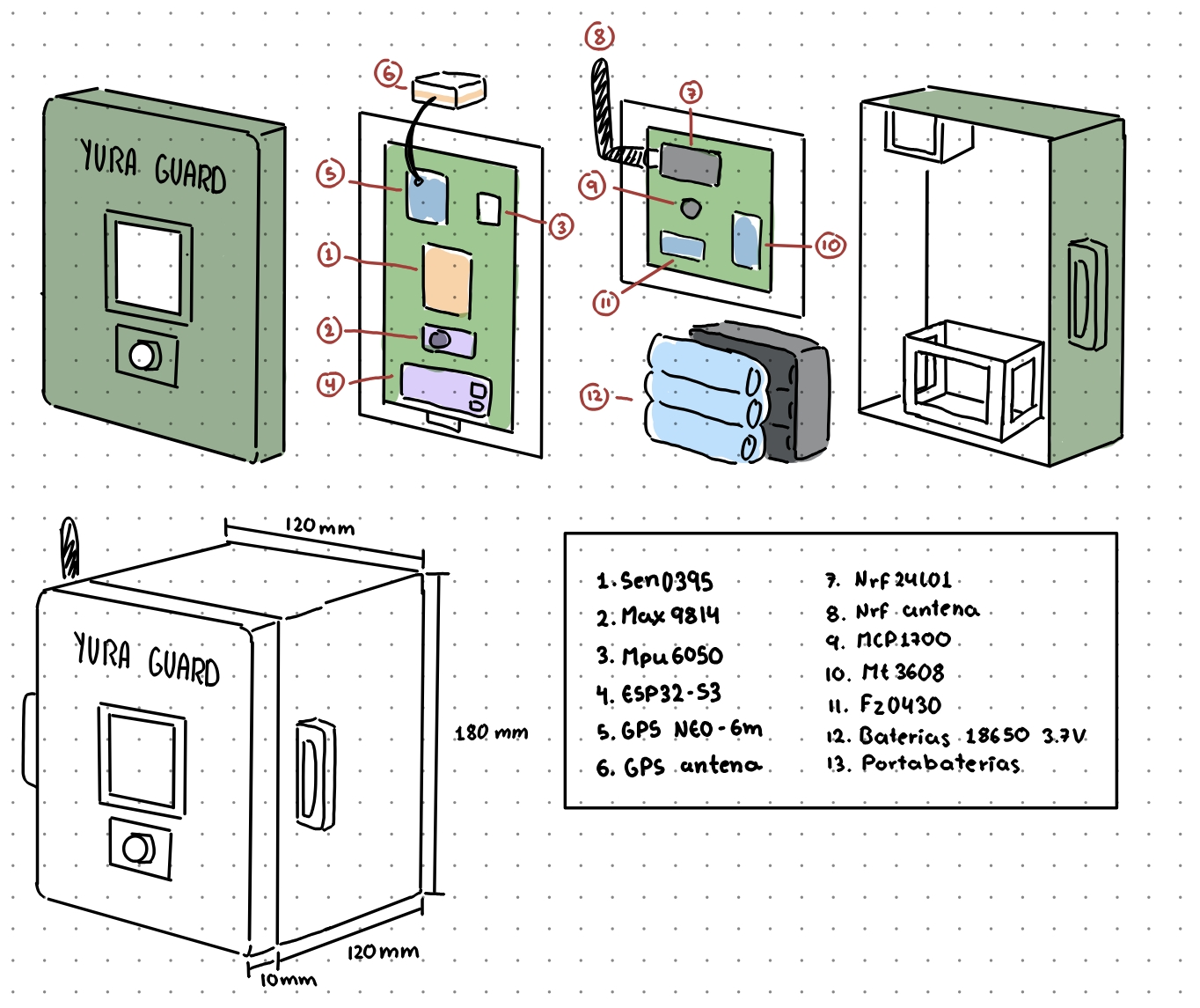
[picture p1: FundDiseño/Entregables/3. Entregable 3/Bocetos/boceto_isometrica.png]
Vista isométrica


**Descripción:** Vista tridimensional que muestra la forma general de la carcasa, la ubicación del display frontal y el asa lateral.

---

## Boceto 2: Vistas Ortogonales

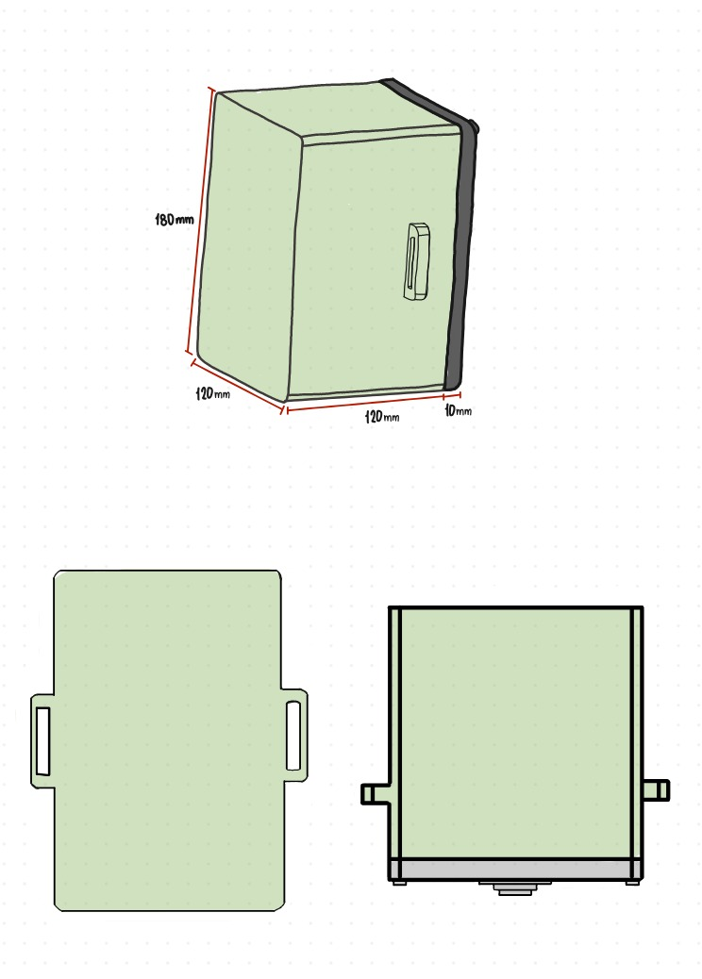
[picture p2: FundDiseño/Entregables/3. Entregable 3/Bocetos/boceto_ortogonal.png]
Vistas ortogonales


**Descripción:** Representación técnica en 2D mostrando las vistas frontal, lateral y superior.

---

## Dimensiones de ambos bocetos

- **Alto:** 180 mm
- **Ancho:** 120 mm
- **Profundidad:** 120 mm
- **Espesor de la tapa:** 10 mm

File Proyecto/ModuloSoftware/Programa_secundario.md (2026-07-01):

# Dispositivo receptor y envío de datos a la aplicación:

```
// =========================================================
// RECEPTOR / PUENTE YURAGUARD
// Recibe datos del dispositivo YuraGuard por medio del nRF24L01
// y los envía a la app por BLE en formato JSON.
// =========================================================

#include <SPI.h>
#include <RF24.h>

#include <BLEDevice.h>
#include <BLEServer.h>
#include <BLEUtils.h>
#include <BLE2902.h>

// ======================
// CONFIGURACIÓN GENERAL
// ======================
#define DEVICE_NAME "YuraGuard"

// True si se desea que la app reciba datos ni bien se inicia, false para poder usar el botón de encendido de la app jahsja (esto ya no sería necesario)
#define SISTEMA_ACTIVO_INICIAL true

// Tiempo para mostrar estado en Serial cuando no llegan paquetes
#define TIEMPO_MENSAJE_ESTADO_MS 3000UL

// Tiempo para reintentar iniciar nRF si no fue detectado
#define TIEMPO_REINTENTO_NRF_MS 5000UL

// ======================
// PINES nRF24L01
// ======================
#define NRF_CE   14
#define NRF_CSN  10
#define NRF_SCK  12
#define NRF_MOSI 11
#define NRF_MISO 13

RF24 radio(NRF_CE, NRF_CSN);
const byte address[6] = "YURA1";

bool nrfOk = false;
unsigned long ultimoReintentoNRF = 0;

// ======================
// BLE - APP INVENTOR
// UUID tipo UART BLE
// ======================
#define SERVICE_UUID        "6E400001-B5A3-F393-E0A9-E50E24DCCA9E"
#define CHARACTERISTIC_RX   "6E400002-B5A3-F393-E0A9-E50E24DCCA9E"  // App -> ESP32 negro
#define CHARACTERISTIC_TX   "6E400003-B5A3-F393-E0A9-E50E24DCCA9E"  // ESP32 negro -> App

BLEServer *bleServer = nullptr;
BLECharacteristic *txCharacteristic = nullptr;

bool appConectada = false;
bool sistemaActivo = SISTEMA_ACTIVO_INICIAL;

// Declaraciones adelantadas usadas por los callbacks BLE
void enviarEstadoBLE(const char *evento);

// ======================
// CÓDIGOS RECIBIDOS DE YURAGUARD
// ======================
#define SONIDO_BOSQUE       0
#define SONIDO_ACTIVIDAD    1   // motosierra + maquinaria agrupadas
#define SONIDO_RESERVADO    2
#define SONIDO_VOZ          3

#define PELIGRO_NORMAL      0
#define PELIGRO_TALA        1   // actividad humana / posible tala
#define PELIGRO_BATERIA     2

// ======================
// PAQUETE RECIBIDO DE YURAGUARD
// Tamaño esperado: 26 bytes.
// ======================
struct __attribute__((packed)) YuraPacket {
  uint32_t contador;

  uint8_t sonido;      // 0 bosque, 1 actividad_humana, 2 reservado, 3 voz_humana
  uint8_t presencia;   // 0 no, 1 si
  uint8_t caida;       // 0 no, 1 si
  uint8_t peligro;     // 0 normal, 1 tala/actividad, 2 bateria
  uint8_t bateria;     // 0 a 100

  float lat;
  float lng;
  float alt;
  float hdop;

  uint8_t satelites;
};

unsigned long ultimoMensajeEstado = 0;
unsigned long ultimoPaqueteMs = 0;
YuraPacket ultimoPaquete;
bool hayPaqueteValido = false;

// ======================
// BLE CALLBACKS
// ======================
class ServerCallbacks : public BLEServerCallbacks {
  void onConnect(BLEServer *pServer) override {
    appConectada = true;
    Serial.println("BLE: app conectada.");
  }

  void onDisconnect(BLEServer *pServer) override {
    appConectada = false;
    Serial.println("BLE: app desconectada. Reiniciando advertising...");
    delay(100);
    pServer->startAdvertising();
  }
};

class RXCallbacks : public BLECharacteristicCallbacks {
  void onWrite(BLECharacteristic *pCharacteristic) override {
    String comando = String(pCharacteristic->getValue().c_str());
    comando.trim();
    comando.toUpperCase();

    Serial.print("BLE comando recibido: ");
    Serial.println(comando);

    if (comando == "ON" || comando == "1" || comando == "START") {
      sistemaActivo = true;
      Serial.println("Sistema activado desde app.");
      enviarEstadoBLE("sistema_activado");
    }
    else if (comando == "OFF" || comando == "0" || comando == "STOP") {
      sistemaActivo = false;
      Serial.println("Sistema apagado desde app.");
      enviarEstadoBLE("sistema_apagado");
    }
    else if (comando == "PING" || comando == "ESTADO") {
      enviarEstadoBLE("estado");
    }
    else {
      Serial.println("Comando no reconocido. Usa ON, OFF, PING o ESTADO.");
      enviarEstadoBLE("comando_no_reconocido");
    }
  }
};

// ======================
// CONVERSIÓN A TEXTO
// ======================
const char* textoSonido(uint8_t sonido) {
  switch (sonido) {
    case SONIDO_BOSQUE:
      return "bosque";
    case SONIDO_ACTIVIDAD:
      return "actividad_humana";   // motosierra + maquinaria agrupadas
    case SONIDO_RESERVADO:
      return "reservado";
    case SONIDO_VOZ:
      return "voz_humana";
    default:
      return "desconocido";
  }
}

const char* textoSiNo(uint8_t valor) {
  return valor ? "si" : "no";
}

const char* textoPeligro(uint8_t peligro) {
  switch (peligro) {
    case PELIGRO_NORMAL:
      return "normal";
    case PELIGRO_TALA:
      return "tala";
    case PELIGRO_BATERIA:
      return "bateria";
    default:
      return "desconocido";
  }
}

// ======================
// CREAR JSON PARA APP INVENTOR
// Mantiene las claves antiguas y agrega contador, satelites, hdop y activo.
// ======================
String crearJSON(const YuraPacket &data) {
  String json;
  json.reserve(220);

  json += "{";
  json += "\"contador\":" + String(data.contador) + ",";
  json += "\"sonido\":\"" + String(textoSonido(data.sonido)) + "\",";
  json += "\"presencia\":\"" + String(textoSiNo(data.presencia)) + "\",";
  json += "\"caida\":\"" + String(textoSiNo(data.caida)) + "\",";
  json += "\"peligro\":\"" + String(textoPeligro(data.peligro)) + "\",";
  json += "\"bateria\":" + String(data.bateria) + ",";
  json += "\"lat\":" + String(data.lat, 6) + ",";
  json += "\"lon\":" + String(data.lng, 6) + ",";
  json += "\"alt\":" + String(data.alt, 1) + ",";
  json += "\"satelites\":" + String(data.satelites) + ",";
  json += "\"hdop\":" + String(data.hdop, 2) + ",";
  json += "\"activo\":\"" + String(sistemaActivo ? "si" : "no") + "\"";
  json += "}";

  return json;
}

String crearJSONEstado(const char *evento) {
  String json;
  json.reserve(120);

  json += "{";
  json += "\"evento\":\"" + String(evento) + "\",";
  json += "\"ble\":\"" + String(appConectada ? "conectado" : "desconectado") + "\",";
  json += "\"sistema\":\"" + String(sistemaActivo ? "activo" : "apagado") + "\",";
  json += "\"nrf\":\"" + String(nrfOk ? "ok" : "no_detectado") + "\",";
  json += "\"hay_datos\":\"" + String(hayPaqueteValido ? "si" : "no") + "\"";
  json += "}";

  return json;
}

// ======================
// ENVIAR A LA APP POR BLE
// ======================
void enviarBLE(const String &json, bool forzarEnvio = false) {
  if (!appConectada) {
    Serial.println("BLE: no se envia, app no conectada.");
    return;
  }

  if (!sistemaActivo && !forzarEnvio) {
    Serial.println("BLE: no se envia paquete, sistema apagado.");
    return;
  }

  if (txCharacteristic == nullptr) {
    Serial.println("BLE: TX characteristic no inicializada.");
    return;
  }

  txCharacteristic->setValue(json.c_str());
  txCharacteristic->notify();

  Serial.print("BLE JSON enviado: ");
  Serial.println(json);
}

void enviarEstadoBLE(const char *evento) {
  String json = crearJSONEstado(evento);
  enviarBLE(json, true);
}

// ======================
// IMPRIMIR PAQUETE EN SERIAL
// ======================
void imprimirPaquete(const YuraPacket &data) {
  Serial.println("========== PAQUETE RECIBIDO ==========");

  Serial.print("Contador: ");
  Serial.println(data.contador);

  Serial.print("Sonido: ");
  Serial.println(textoSonido(data.sonido));

  Serial.print("Presencia: ");
  Serial.println(textoSiNo(data.presencia));

  Serial.print("Caida: ");
  Serial.println(textoSiNo(data.caida));

  Serial.print("Peligro: ");
  Serial.println(textoPeligro(data.peligro));

  Serial.print("Bateria: ");
  Serial.print(data.bateria);
  Serial.println("%");

  Serial.print("Latitud: ");
  Serial.println(data.lat, 6);

  Serial.print("Longitud: ");
  Serial.println(data.lng, 6);

  Serial.print("Altitud: ");
  Serial.println(data.alt, 1);

  Serial.print("Satelites: ");
  Serial.println(data.satelites);

  Serial.print("HDOP: ");
  Serial.println(data.hdop, 2);
}

// ======================
// INICIAR NRF24L01
// No bloquea el programa si falla.
// ======================
bool iniciarNRF() {
  SPI.begin(NRF_SCK, NRF_MISO, NRF_MOSI, NRF_CSN);

  if (!radio.begin()) {
    Serial.println("ERROR: NRF24L01 no detectado en receptor negro.");
    Serial.println("Revisa VCC 3.3V, GND, CE, CSN, SCK, MOSI y MISO.");
    nrfOk = false;
    return false;
  }

  radio.setChannel(90);
  radio.setDataRate(RF24_250KBPS);
  radio.setPALevel(RF24_PA_LOW);

  radio.setAutoAck(true);
  radio.setRetries(5, 15);
  radio.setPayloadSize(sizeof(YuraPacket));

  radio.openReadingPipe(1, address);
  radio.startListening();
  radio.flush_rx();

  nrfOk = true;

  Serial.println("NRF24L01 receptor detectado.");
  Serial.print("Tamano paquete receptor: ");
  Serial.print(sizeof(YuraPacket));
  Serial.println(" bytes");

  if (sizeof(YuraPacket) <= 32) {
    Serial.println("Paquete compatible con nRF24L01.");
  } else {
    Serial.println("ERROR: paquete mayor a 32 bytes. nRF24L01 no puede enviarlo.");
  }

  Serial.println("Receptor nRF listo.");
  return true;
}

void reintentarNRFSiHaceFalta() {
  if (nrfOk) return;

  if (millis() - ultimoReintentoNRF >= TIEMPO_REINTENTO_NRF_MS) {
    ultimoReintentoNRF = millis();
    Serial.println("Reintentando iniciar nRF24L01...");
    iniciarNRF();
  }
}

// ======================
// INICIAR BLE
// ======================
void iniciarBLE() {
  BLEDevice::init(DEVICE_NAME);
  BLEDevice::setMTU(185);

  bleServer = BLEDevice::createServer();
  bleServer->setCallbacks(new ServerCallbacks());

  BLEService *service = bleServer->createService(SERVICE_UUID);

  txCharacteristic = service->createCharacteristic(
    CHARACTERISTIC_TX,
    BLECharacteristic::PROPERTY_NOTIFY
  );
  txCharacteristic->addDescriptor(new BLE2902());

  BLECharacteristic *rxCharacteristic = service->createCharacteristic(
    CHARACTERISTIC_RX,
    BLECharacteristic::PROPERTY_WRITE
  );
  rxCharacteristic->setCallbacks(new RXCallbacks());

  service->start();

  BLEAdvertising *advertising = BLEDevice::getAdvertising();
  advertising->addServiceUUID(SERVICE_UUID);
  advertising->setScanResponse(true);
  advertising->setMinPreferred(0x06);
  advertising->setMinPreferred(0x12);

  BLEDevice::startAdvertising();

  Serial.print("BLE listo. Busca el dispositivo: ");
  Serial.println(DEVICE_NAME);
}

// ======================
// LEER PAQUETE NRF
// ======================
bool leerPaqueteNRF(YuraPacket &data) {
  if (!nrfOk) return false;
  if (!radio.available()) return false;

  // Si llegaron varios paquetes, nos quedamos con el último.
  while (radio.available()) {
    radio.read(&data, sizeof(data));
  }

  return true;
}

// ======================
// MENSAJE DE ESTADO SERIAL
// ======================
void imprimirEstadoPeriodico() {
  if (millis() - ultimoMensajeEstado < TIEMPO_MENSAJE_ESTADO_MS) return;
  ultimoMensajeEstado = millis();

  Serial.println("---------- ESTADO RECEPTOR ----------");
  Serial.print("nRF: ");
  Serial.println(nrfOk ? "OK" : "NO DETECTADO");

  Serial.print("BLE conectado: ");
  Serial.println(appConectada ? "SI" : "NO");

  Serial.print("Sistema activo: ");
  Serial.println(sistemaActivo ? "SI" : "NO");

  Serial.print("Hay paquete recibido: ");
  Serial.println(hayPaqueteValido ? "SI" : "NO");

  if (hayPaqueteValido) {
    Serial.print("Ultimo paquete hace: ");
    Serial.print((millis() - ultimoPaqueteMs) / 1000.0, 1);
    Serial.println(" s");
  } else {
    Serial.println("Esperando paquetes del ESP32 morado...");
  }

  Serial.println("--------------------------------------");
  Serial.println();
}

// ======================
// SETUP
// ======================
void setup() {
  Serial.begin(115200);
  delay(1500);

  Serial.println();
  Serial.println("========================================");
  Serial.println("ESP32 NEGRO - RECEPTOR PUENTE YURAGUARD");
  Serial.println("========================================");

  Serial.print("Sistema activo inicial: ");
  Serial.println(sistemaActivo ? "SI" : "NO");

  iniciarNRF();
  iniciarBLE();

  Serial.println("Listo. Esperando paquetes del ESP32 morado...");
  Serial.println();
}

// ======================
// LOOP
// ======================
void loop() {
  reintentarNRFSiHaceFalta();

  YuraPacket data;

  if (leerPaqueteNRF(data)) {
    ultimoPaquete = data;
    hayPaqueteValido = true;
    ultimoPaqueteMs = millis();

    imprimirPaquete(data);

    String json = crearJSON(data);

    Serial.print("JSON creado: ");
    Serial.println(json);

    enviarBLE(json);

    Serial.println("======================================");
    Serial.println();
  }

  imprimirEstadoPeriodico();
}

```

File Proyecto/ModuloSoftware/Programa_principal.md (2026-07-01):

# Dispositivo YuraGuard

```
/* =========================================================
   YURAGUARD
   Envia el paquete con el siguiente contenido:

   contador, sonido, presencia, caida, peligro, bateria,
   lat, lng, alt, hdop, satelites

   IA Edge Impulse:
   - bosque = normal
   - voz_humana + actividad_humana = alerta
   - actividad_humana representa motosierra + maquinaria
   ========================================================= */

#define EIDSP_QUANTIZE_FILTERBANK 0
#include <MarthCage-project-1_inferencing.h>

#include <Arduino.h>
#include <Wire.h>
#include <TinyGPSPlus.h>
#include <Adafruit_MPU6050.h>
#include <Adafruit_Sensor.h>
#include <SPI.h>
#include <RF24.h>
#include <math.h>
#include <string.h>

// ======================
// PINES
// ======================
#define MIC_PIN 4

#define PIN_GPS_RX_ESP 10
#define PIN_GPS_TX_ESP 9

#define PIN_RADAR_RX_ESP 16
#define PIN_RADAR_TX_ESP 18

#define PIN_MPU_SDA 21
#define PIN_MPU_SCL 20

#define NRF_CE   35
#define NRF_CSN  36
#define NRF_SCK  37
#define NRF_MOSI 38
#define NRF_MISO 39

// Bateria FZ0430: S/OUT -> GPIO1
#define PIN_BATERIA 1

// Calibrado con pack real 3.54 V y lectura ADC aprox. 0.629 V
#define FACTOR_FZ0430 5.63f

// Escala de porcentaje para prototipo
#define VOLTAJE_BATERIA_MIN 3.30f
#define VOLTAJE_BATERIA_MAX 3.70f

// Cambia a 0 para probar sin FZ0430/bateria
#define USAR_SENSOR_BATERIA 1

// ======================
// AJUSTES
// ======================
#define AUDIO_GAIN 2
#define RMS_ALERTA_MIN 120
// Deteccion mejorada de caida con MPU6050
// Fase 1: caida libre si la magnitud baja de 0.55G
// Fase 2: impacto si luego sube sobre 2.0G en menos de 1 segundo
#define CAIDA_LIBRE_G_MAX 0.55f
#define CAIDA_IMPACTO_G_MIN 2.00f
#define CAIDA_TIEMPO_MAX_MS 1000UL

// La caida detectada queda pendiente hasta que se envie el siguiente paquete NRF

// Si quieres que sonido de alerta necesite presencia radar, pon 1
#define EXIGIR_PRESENCIA_PARA_TALA 0

// ======================
// CODIGOS DEL PAQUETE
// Deben coincidir con el ESP32 negro
// ======================
#define SONIDO_BOSQUE       0
#define SONIDO_ACTIVIDAD    1   // motosierra + maquinaria agrupadas
#define SONIDO_RESERVADO    2
#define SONIDO_VOZ          3

#define PELIGRO_NORMAL      0
#define PELIGRO_TALA        1
#define PELIGRO_BATERIA     2

// ======================
// OBJETOS
// ======================
HardwareSerial GPSSerial(2);
HardwareSerial RadarSerial(1);
TinyGPSPlus gps;
Adafruit_MPU6050 mpu;

RF24 radio(NRF_CE, NRF_CSN);
const byte address[6] = "YURA1";

// ======================
// PAQUETE NRF
// IMPORTANTE: igual al struct del ESP32 negro
// Tamaño esperado: 26 bytes
// ======================
struct __attribute__((packed)) YuraPacket {
  uint32_t contador;

  uint8_t sonido;
  uint8_t presencia;
  uint8_t caida;
  uint8_t peligro;
  uint8_t bateria;

  float lat;
  float lng;
  float alt;
  float hdop;

  uint8_t satelites;
};

// ======================
// EDGE IMPULSE AUDIO
// ======================
typedef struct {
  signed short *buffers[2];
  unsigned char buf_select;
  volatile unsigned char buf_ready;
  unsigned int buf_count;
  unsigned int n_samples;
} inference_t;

static inference_t inference;
static bool debug_nn = false;
static int print_results = -(EI_CLASSIFIER_SLICES_PER_MODEL_WINDOW);
static bool record_status = true;
static int adc_center = 1430;

volatile int32_t audio_peak = 0;
volatile float audio_rms = 0.0f;
volatile bool pausarAudioADC = false;

// Estado compartido de caida mejorada
volatile bool caidaPendiente = false;
volatile bool posibleCaidaLibre = false;
volatile unsigned long tiempoCaidaLibre = 0;
volatile float ultimaVibracionMPU = 0.0f;
volatile float ultimaGMPU = 1.0f;

// ======================
// ESTADO
// ======================
bool mpuOk = false;
bool nrfOk = false;
bool iaOk = false;
uint32_t contador = 0;

// ======================
// PROTOTIPOS
// ======================
void feedGPS();
void calibrar_microfono();
bool microphone_inference_start(uint32_t n_samples);
bool microphone_inference_record();
int microphone_audio_signal_get_data(size_t offset, size_t length, float *out_ptr);
void microphone_inference_end();
void capture_samples(void* arg);
void tareaCaidaMPU(void* arg);

void inicializarSensores();
void inicializarNRF();
void inicializarIA();

uint8_t clasificarSonido(const ei_impulse_result_t &result);
uint8_t leerPresenciaRadar();
uint8_t leerCaidaMPU(float *vibracionOut);
uint8_t leerBateria();
uint8_t analizarPeligro(uint8_t sonido, uint8_t presencia, uint8_t caida, uint8_t bateria);
void crearYEnviarPaquete(uint8_t sonido);
void imprimirPaquete(const YuraPacket &data);

String textoSonido(uint8_t sonido);
String textoSiNo(uint8_t v);
String textoPeligro(uint8_t peligro);

// ======================
// SETUP
// ======================
void setup() {
  Serial.begin(115200);
  delay(1500);

  Serial.println();
  Serial.println("INICIANDO YURAGUARD MORADO - ENVIO MINIMO");

  inicializarSensores();
  inicializarNRF();
  inicializarIA();

  Serial.print("Tamano YuraPacket: ");
  Serial.print(sizeof(YuraPacket));
  Serial.println(" bytes");
  Serial.println("Sistema listo.");
  Serial.println();
}

// ======================
// LOOP
// ======================
void loop() {
  feedGPS();

  if (!iaOk) {
    delay(500);
    return;
  }

  if (!microphone_inference_record()) {
    Serial.println("ERR: fallo al grabar audio");
    return;
  }

  signal_t signal;
  signal.total_length = EI_CLASSIFIER_SLICE_SIZE;
  signal.get_data = &microphone_audio_signal_get_data;

  ei_impulse_result_t result = {0};
  EI_IMPULSE_ERROR r = run_classifier_continuous(&signal, &result, debug_nn);

  if (r != EI_IMPULSE_OK) {
    Serial.print("ERR: clasificador fallo: ");
    Serial.println((int)r);
    return;
  }

  // Solo enviamos cuando ya hay una ventana completa de IA
  if (++print_results >= EI_CLASSIFIER_SLICES_PER_MODEL_WINDOW) {
    uint8_t sonido = clasificarSonido(result);
    crearYEnviarPaquete(sonido);
    print_results = 0;
  }
}

// ======================
// INICIALIZACION
// ======================
void inicializarSensores() {
  analogReadResolution(12);
  analogSetPinAttenuation(MIC_PIN, ADC_11db);
  pinMode(PIN_BATERIA, INPUT);
  analogSetPinAttenuation(PIN_BATERIA, ADC_11db);

  GPSSerial.begin(9600, SERIAL_8N1, PIN_GPS_RX_ESP, PIN_GPS_TX_ESP);
  RadarSerial.begin(115200, SERIAL_8N1, PIN_RADAR_RX_ESP, PIN_RADAR_TX_ESP);

  Wire.begin(PIN_MPU_SDA, PIN_MPU_SCL);
  Wire.setClock(400000);

  mpuOk = mpu.begin(0x68, &Wire);
  if (mpuOk) {
    mpu.setAccelerometerRange(MPU6050_RANGE_8_G);
    mpu.setGyroRange(MPU6050_RANGE_500_DEG);
    mpu.setFilterBandwidth(MPU6050_BAND_21_HZ);
    Serial.println("MPU6050 OK");

    BaseType_t tareaOk = xTaskCreatePinnedToCore(
      tareaCaidaMPU,
      "TareaCaidaMPU",
      4096,
      NULL,
      1,
      NULL,
      1
    );

    if (tareaOk == pdPASS) {
      Serial.println("Deteccion mejorada de caida OK");
    } else {
      Serial.println("ERR: no se pudo iniciar tarea de caida");
    }
  } else {
    Serial.println("MPU6050 no detectado");
  }
}

void inicializarNRF() {
  SPI.begin(NRF_SCK, NRF_MISO, NRF_MOSI, NRF_CSN);

  nrfOk = radio.begin();
  if (!nrfOk) {
    Serial.println("NRF24L01 no detectado");
    return;
  }

  radio.setChannel(90);
  radio.setDataRate(RF24_250KBPS);
  radio.setPALevel(RF24_PA_LOW);
  radio.setAutoAck(true);
  radio.setRetries(5, 15);
  radio.setPayloadSize(sizeof(YuraPacket));
  radio.openWritingPipe(address);
  radio.stopListening();

  Serial.println("NRF24L01 OK");
}

void inicializarIA() {
  Serial.println("Calibrando microfono...");
  calibrar_microfono();

  Serial.print("ADC center: ");
  Serial.println(adc_center);

  run_classifier_init();

  if (!microphone_inference_start(EI_CLASSIFIER_SLICE_SIZE)) {
    Serial.println("ERR: no se pudo iniciar buffer de audio");
    iaOk = false;
    return;
  }

  iaOk = true;
  Serial.println("IA OK");
}

// ======================
// GPS
// ======================
void feedGPS() {
  while (GPSSerial.available()) {
    gps.encode(GPSSerial.read());
  }
}

// ======================
// CLASIFICACION IA
// ======================
uint8_t clasificarSonido(const ei_impulse_result_t &result) {
  float p_bosque = 0.0f;
  float p_voz = 0.0f;
  float p_actividad = 0.0f;

  for (size_t ix = 0; ix < EI_CLASSIFIER_LABEL_COUNT; ix++) {
    const char *label = result.classification[ix].label;
    float value = result.classification[ix].value;

    if (strcmp(label, "bosque") == 0 || strcmp(label, "BOSQUE") == 0) {
      p_bosque = value;
    }
    else if (
      strcmp(label, "voz_humana") == 0 ||
      strcmp(label, "voz humana") == 0 ||
      strcmp(label, "VOZ_HUMANA") == 0 ||
      strcmp(label, "VOZ HUMANA") == 0
    ) {
      p_voz = value;
    }
    else if (
      strcmp(label, "actividad_humana") == 0 ||
      strcmp(label, "actividad humana") == 0 ||
      strcmp(label, "ACTIVIDAD_HUMANA") == 0 ||
      strcmp(label, "ACTIVIDAD HUMANA") == 0
    ) {
      p_actividad = value;
    }
  }

  float p_alerta = p_voz + p_actividad;

  if (audio_peak >= 32000) {
    // Audio saturado: se conserva el resultado, pero seria bueno bajar AUDIO_GAIN.
  }

  if (p_alerta > p_bosque && audio_rms > RMS_ALERTA_MIN) {
    if (p_voz >= p_actividad) {
      return SONIDO_VOZ;
    }
    return SONIDO_ACTIVIDAD;
  }

  return SONIDO_BOSQUE;
}

// ======================
// SENSORES
// ======================
uint8_t leerPresenciaRadar() {
  uint8_t presencia = 0;

  if (RadarSerial.available()) {
    presencia = 1;
    while (RadarSerial.available()) {
      RadarSerial.read();
    }
  }

  return presencia;
}

void tareaCaidaMPU(void* arg) {
  (void)arg;

  while (true) {
    if (!mpuOk) {
      vTaskDelay(pdMS_TO_TICKS(200));
      continue;
    }

    sensors_event_t acc, gyro, temp;
    mpu.getEvent(&acc, &gyro, &temp);

    float accMag = sqrt(
      acc.acceleration.x * acc.acceleration.x +
      acc.acceleration.y * acc.acceleration.y +
      acc.acceleration.z * acc.acceleration.z
    );

    float gActual = accMag / 9.81f;
    float vibracion = fabs(accMag - 9.81f);
    unsigned long ahora = millis();

    ultimaGMPU = gActual;
    ultimaVibracionMPU = vibracion;

    // Fase 1: posible caida libre.
    if (!posibleCaidaLibre && gActual < CAIDA_LIBRE_G_MAX) {
      posibleCaidaLibre = true;
      tiempoCaidaLibre = ahora;
    }

    // Fase 2: impacto fuerte despues de la caida libre.
    if (posibleCaidaLibre &&
        gActual > CAIDA_IMPACTO_G_MIN &&
        (ahora - tiempoCaidaLibre) <= CAIDA_TIEMPO_MAX_MS) {
      caidaPendiente = true;
      posibleCaidaLibre = false;
    }

    // Si no hubo impacto a tiempo, se cancela la posible caida.
    if (posibleCaidaLibre &&
        (ahora - tiempoCaidaLibre) > CAIDA_TIEMPO_MAX_MS) {
      posibleCaidaLibre = false;
    }

    vTaskDelay(pdMS_TO_TICKS(20));
  }
}

uint8_t leerCaidaMPU(float *vibracionOut) {
  if (!mpuOk) {
    *vibracionOut = 0.0f;
    return 0;
  }

  *vibracionOut = ultimaVibracionMPU;

  // Se consume la caida pendiente para enviarla una sola vez por NRF.
  if (caidaPendiente) {
    caidaPendiente = false;
    return 1;
  }

  return 0;
}

uint8_t leerBateria() {
#if USAR_SENSOR_BATERIA == 0
  return 100;
#else
  // Pausa temporal de audio para evitar conflicto ADC con el MAX9814.
  pausarAudioADC = true;
  delay(30);

  analogSetPinAttenuation(PIN_BATERIA, ADC_11db);

  for (int i = 0; i < 10; i++) {
    analogRead(PIN_BATERIA);
    delay(2);
  }

  const int muestras = 25;
  int lecturas[muestras];

  for (int i = 0; i < muestras; i++) {
    lecturas[i] = analogRead(PIN_BATERIA);
    delay(4);
  }

  analogSetPinAttenuation(MIC_PIN, ADC_11db);
  pausarAudioADC = false;

  // Ordenar para mediana
  for (int i = 0; i < muestras - 1; i++) {
    for (int j = i + 1; j < muestras; j++) {
      if (lecturas[j] < lecturas[i]) {
        int tmp = lecturas[i];
        lecturas[i] = lecturas[j];
        lecturas[j] = tmp;
      }
    }
  }

  int lecturaMediana = lecturas[muestras / 2];
  float voltajeADC = (lecturaMediana / 4095.0f) * 3.3f;
  float voltajeBateria = voltajeADC * FACTOR_FZ0430;

  if (lecturaMediana < 20) {
    return 0;
  }

  float porcentaje = ((voltajeBateria - VOLTAJE_BATERIA_MIN) /
                     (VOLTAJE_BATERIA_MAX - VOLTAJE_BATERIA_MIN)) * 100.0f;

  if (porcentaje > 100.0f) porcentaje = 100.0f;
  if (porcentaje < 0.0f) porcentaje = 0.0f;

  return (uint8_t)porcentaje;
#endif
}

uint8_t analizarPeligro(uint8_t sonido, uint8_t presencia, uint8_t caida, uint8_t bateria) {
  bool sonidoAlerta = (sonido == SONIDO_ACTIVIDAD || sonido == SONIDO_VOZ);

#if EXIGIR_PRESENCIA_PARA_TALA == 1
  if (sonidoAlerta && presencia == 1) {
    return PELIGRO_TALA;
  }
#else
  if (sonidoAlerta) {
    return PELIGRO_TALA;
  }
#endif

  if (bateria <= 20) {
    return PELIGRO_BATERIA;
  }

  return PELIGRO_NORMAL;
}

// ======================
// CREAR Y ENVIAR PAQUETE
// ======================
void crearYEnviarPaquete(uint8_t sonido) {
  feedGPS();

  float vibracion = 0.0f;
  uint8_t caida = leerCaidaMPU(&vibracion);
  uint8_t presencia = leerPresenciaRadar();
  uint8_t bateria = leerBateria();

  float lat = 0.0f;
  float lng = 0.0f;
  float alt = 0.0f;
  float hdop = 99.99f;
  uint8_t satelites = 0;

  if (gps.location.isValid()) {
    lat = gps.location.lat();
    lng = gps.location.lng();
  }

  if (gps.altitude.isValid()) {
    alt = gps.altitude.meters();
  }

  if (gps.hdop.isValid()) {
    hdop = gps.hdop.hdop();
  }

  if (gps.satellites.isValid()) {
    satelites = gps.satellites.value();
  }

  uint8_t peligro = analizarPeligro(sonido, presencia, caida, bateria);

  YuraPacket data;
  data.contador = contador++;
  data.sonido = sonido;
  data.presencia = presencia;
  data.caida = caida;
  data.peligro = peligro;
  data.bateria = bateria;
  data.lat = lat;
  data.lng = lng;
  data.alt = alt;
  data.hdop = hdop;
  data.satelites = satelites;

  if (nrfOk) {
    bool enviado = radio.write(&data, sizeof(data));
    if (!enviado) {
      Serial.println("NRF envio: FALLO");
    }
  } else {
    Serial.println("NRF no disponible");
  }

  imprimirPaquete(data);
}

void imprimirPaquete(const YuraPacket &data) {
  Serial.println("========== PAQUETE ENVIADO ==========");

  Serial.print("Contador: ");
  Serial.println(data.contador);

  Serial.print("Sonido: ");
  Serial.println(textoSonido(data.sonido));

  Serial.print("Presencia: ");
  Serial.println(textoSiNo(data.presencia));

  Serial.print("Caida: ");
  Serial.println(textoSiNo(data.caida));

  Serial.print("Peligro: ");
  Serial.println(textoPeligro(data.peligro));

  Serial.print("Bateria: ");
  Serial.print(data.bateria);
  Serial.println("%");

  Serial.print("Latitud: ");
  Serial.println(data.lat, 6);

  Serial.print("Longitud: ");
  Serial.println(data.lng, 6);

  Serial.print("Altitud: ");
  Serial.println(data.alt, 1);

  Serial.print("Satelites: ");
  Serial.println(data.satelites);

  Serial.print("HDOP: ");
  Serial.println(data.hdop, 2);

  Serial.println("=====================================");
  Serial.println();
}

// ======================
// TEXTOS
// ======================
String textoSonido(uint8_t sonido) {
  if (sonido == SONIDO_BOSQUE) return "bosque";
  if (sonido == SONIDO_ACTIVIDAD) return "actividad humana";
  if (sonido == SONIDO_VOZ) return "voz humana";
  return "reservado";
}

String textoSiNo(uint8_t v) {
  return v ? "SI" : "NO";
}

String textoPeligro(uint8_t peligro) {
  if (peligro == PELIGRO_TALA) return "alerta / posible tala o actividad humana";
  if (peligro == PELIGRO_BATERIA) return "bateria baja";
  return "normal";
}

// ======================
// AUDIO / EDGE IMPULSE
// ======================
void calibrar_microfono() {
  long sum = 0;
  const int N = 2000;

  for (int i = 0; i < N; i++) {
    sum += analogRead(MIC_PIN);
    delayMicroseconds(100);
  }

  adc_center = sum / N;
}

bool microphone_inference_start(uint32_t n_samples) {
  inference.buffers[0] = (signed short *)malloc(n_samples * sizeof(signed short));
  if (inference.buffers[0] == NULL) return false;

  inference.buffers[1] = (signed short *)malloc(n_samples * sizeof(signed short));
  if (inference.buffers[1] == NULL) {
    free(inference.buffers[0]);
    return false;
  }

  inference.buf_select = 0;
  inference.buf_count = 0;
  inference.n_samples = n_samples;
  inference.buf_ready = 0;
  record_status = true;

  BaseType_t task_ok = xTaskCreatePinnedToCore(
    capture_samples,
    "CaptureSamples",
    1024 * 8,
    NULL,
    1,
    NULL,
    0
  );

  return task_ok == pdPASS;
}

void capture_samples(void* arg) {
  (void)arg;

  const uint32_t sample_interval_us = 1000000UL / EI_CLASSIFIER_FREQUENCY;
  int64_t sum_squares = 0;
  int32_t peak = 0;
  unsigned long next_sample_time = micros();

  while (record_status) {
    if (pausarAudioADC) {
      next_sample_time = micros() + sample_interval_us;
      vTaskDelay(1);
      continue;
    }

    while ((long)(micros() - next_sample_time) < 0) {
      // espera para mantener frecuencia de muestreo
    }

    next_sample_time += sample_interval_us;

    int raw = analogRead(MIC_PIN);
    int centered = raw - adc_center;
    int32_t sample32 = centered * AUDIO_GAIN;

    if (sample32 > 32767) sample32 = 32767;
    if (sample32 < -32768) sample32 = -32768;

    int16_t sample16 = (int16_t)sample32;
    inference.buffers[inference.buf_select][inference.buf_count++] = sample16;

    int32_t abs_sample = abs((int)sample16);
    if (abs_sample > peak) peak = abs_sample;
    sum_squares += (int64_t)sample16 * (int64_t)sample16;

    if (inference.buf_count >= inference.n_samples) {
      audio_peak = peak;
      audio_rms = sqrt((float)sum_squares / inference.n_samples);

      inference.buf_select ^= 1;
      inference.buf_count = 0;
      inference.buf_ready = 1;

      peak = 0;
      sum_squares = 0;
      vTaskDelay(1);
    }
  }

  vTaskDelete(NULL);
}

bool microphone_inference_record() {
  while (inference.buf_ready == 0) {
    delay(1);
  }

  inference.buf_ready = 0;
  return true;
}

int microphone_audio_signal_get_data(size_t offset, size_t length, float *out_ptr) {
  numpy::int16_to_float(
    &inference.buffers[inference.buf_select ^ 1][offset],
    out_ptr,
    length
  );

  return 0;
}

void microphone_inference_end() {
  record_status = false;

  if (inference.buffers[0]) free(inference.buffers[0]);
  if (inference.buffers[1]) free(inference.buffers[1]);
}

#if !defined(EI_CLASSIFIER_SENSOR) || EI_CLASSIFIER_SENSOR != EI_CLASSIFIER_SENSOR_MICROPHONE
#error "Invalid model for current sensor."
#endif
```

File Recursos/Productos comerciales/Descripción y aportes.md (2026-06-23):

# Descripción y Aportes de Productos Comerciales

## Producto 1: Guardian 3 (G3) - Rainforest Connection
- **Empresa:** Rainforest Connection (RFCx)
- **Descripción:** Dispositivo de monitoreo bioacústico alimentado por energía solar que se instala en árboles. Combina tres micrófonos de alta sensibilidad (radio de 50m a 1500m), IA y aprendizaje automático para detectar en tiempo real amenazas como tala ilegal, caza furtiva e incendios forestales, enviando alertas a guardaparques mediante una app móvil.
- **Aporte al proyecto:**
  - Valida el uso de monitoreo acústico 24/7 con energía solar
  - Demuestra la efectividad de IA para detección de motosierras y actividad ilegal
  - Sirve como referencia de arquitectura IoT para alertas tempranas
  - Justifica la integración de múltiples sensores de audio
- **Link:** https://rfcx.org/

---

## Producto 2: AudioMoth - Open Acoustic Devices
- **Empresa:** Open Acoustic Devices
- **Descripción:** Dispositivo acústico de bajo costo y hardware abierto que permite grabar sonidos ambientales en bosques. Al integrarse con plataformas como Arbimon, puede identificar patrones acústicos asociados a actividades humanas como motosierras, siendo una alternativa accesible para detección temprana.
- **Aporte al proyecto:**
  - Demuestra la viabilidad de monitoreo acústico con dispositivos de bajo costo
  - Valida el uso de grabación continua para análisis posterior
  - Proporciona un modelo de hardware abierto adaptable
  - Justifica el diseño de sensores acústicos accesibles
- **Link:** https://www.openacousticdevices.info/audiomoth

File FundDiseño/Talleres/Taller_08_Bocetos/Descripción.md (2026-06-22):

# Bocetos - YURA GUARD

## Descripción

Bocetos conceptuales del dispositivo YURA GUARD para la detección de tala ilegal en la Amazonía peruana.

---

## Boceto 1

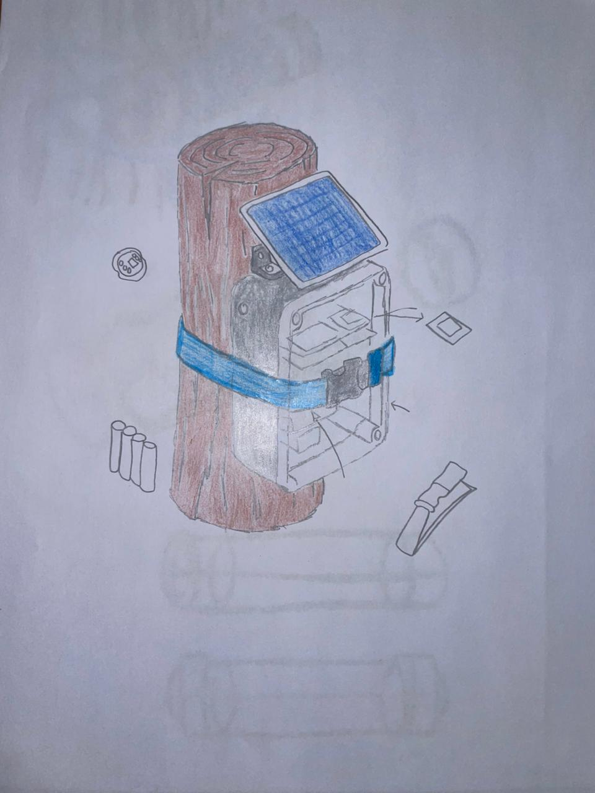
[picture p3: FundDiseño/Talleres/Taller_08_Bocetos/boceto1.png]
Boceto 1


Concepto con diseño modular, carcasa protectora impresa en 3D y fijación al árbol mediante correa de nylon. Incluye compartimento interno para almacenamiento de energía y sistema de captación solar.

---

## Boceto 2

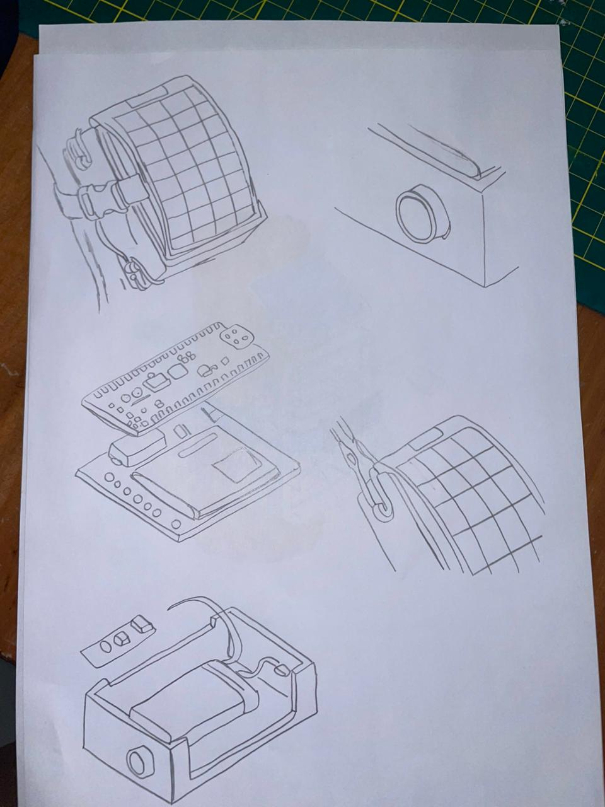
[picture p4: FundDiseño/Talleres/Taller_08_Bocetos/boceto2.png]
Boceto 2


Concepto con panel solar rígido en la parte superior para captar energía. Fijación al tronco con correa de nylon y almacenamiento energético mediante celdas recargables.

---

## Boceto 3

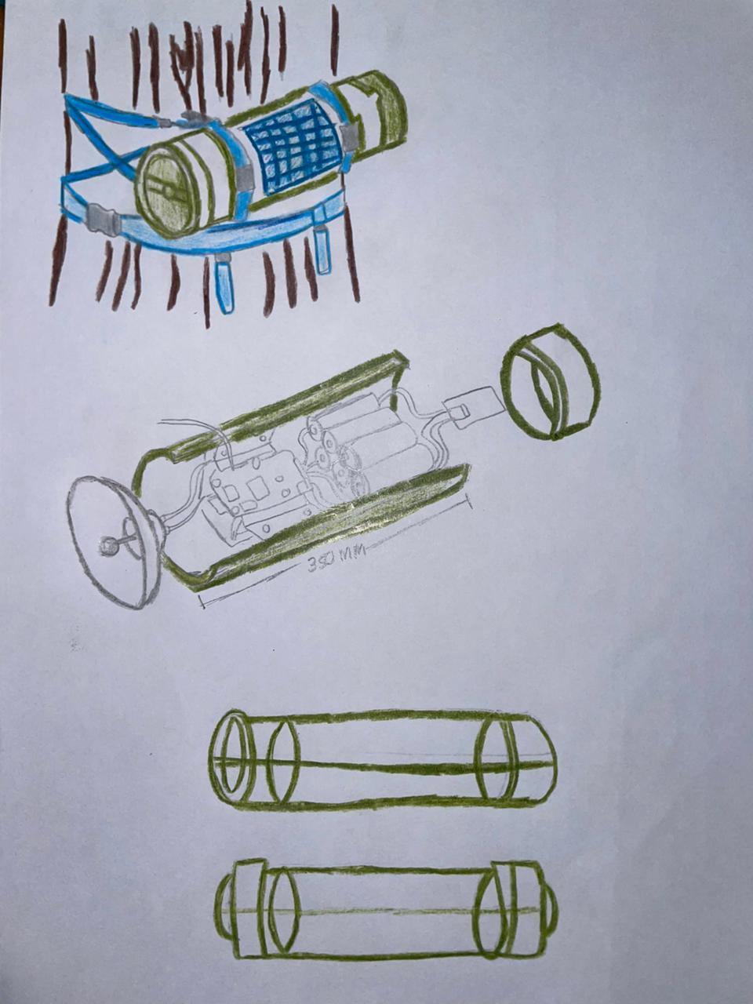
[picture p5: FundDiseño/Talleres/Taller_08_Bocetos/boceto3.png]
Boceto 3


Concepto completo con panel solar inclinado, carcasa protectora y sistema de sujeción al árbol. 

---

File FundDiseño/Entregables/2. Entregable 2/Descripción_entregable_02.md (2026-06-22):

# Entregable 2 - Informe Técnico del Proyecto YURA GUARD

## Descripción

El informe técnico presenta el desarrollo del sistema YURA GUARD para la detección de tala ilegal en la Amazonía peruana.

##  Contenido

El informe incluye:
-  Introducción y problemática
-  Estado de la tecnología 
-  Lista de exigencias 
-  Estructura de funciones 
-  Concepto de solución por dominio 
-  Bocetos de 3 conceptos de solución
-  Evaluación mediante Matriz de Pugh
-  Selección del concepto óptimo
-  Referencias bibliográficas

##  Archivo
- [Informe_Técnico.pdf](Informe_Técnico.pdf)

---

**Grupo 9 | UPCH - Facultad de Ciencias e Ingeniería | 2026**

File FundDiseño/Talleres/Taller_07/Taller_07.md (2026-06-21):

# Lista de exigencias

En el taller se presentó la lista de exigencias del prototipo a realizar

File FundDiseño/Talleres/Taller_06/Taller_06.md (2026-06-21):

# Desk Research

En este taller se inició la búsqueda de información a profundidad para fundamentar el proyecto

## Link a la tabla excel:

https://docs.google.com/spreadsheets/d/1ObdI_YQ0xtc3LZFt-9zmgO_4alu-W7R7P_x90MP62lc/edit?gid=0#gid=0

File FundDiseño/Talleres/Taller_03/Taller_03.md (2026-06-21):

# Estado de arte

En este taller se trabajó en la búsqueda de información para la redacción de la introducción del proyecto. 

## Versión final

### Diseño de un sistema IoT para la detección y alerta temprana de tala ilegal en la amazonía del Perú

Este proyecto de innovación aborda una problemática relacionada con el Objetivo de Desarrollo Sostenible 15 (ODS15): Vida y ecosistema terrestre, propuesto en la Agenda 2030. Este objetivo incluye varias metas relacionadas que evidencian un enfoque integral orientado a la conservación de los ecosistemas terrestres y de la biodiversidad, buscando soluciones que permitan reducir los conflictos entre la actividad humana y la fauna silvestre sin alterar el equilibrio ecológico (1).

En este contexto, el proyecto se alinea con los objetivos estratégicos del Estado peruano para la protección del patrimonio forestal nacional. El sistema funcionará como herramienta para entidades como el  Ministerio del Ambiente (MINAM) y el Servicio Nacional Forestal y de Fauna Silvestre (SERFOR), Su propósito es mejorar la vigilancia en zonas críticas donde hay poco personal,  lo que permitiría obtener datos más precisos para la toma de decisiones informadas y la preservación de la biodiversidad en territorios de difícil acceso(9)(10).

La deforestación se ha convertido en una de las amenazas ambientales más críticas a nivel mundial, especialmente en regiones tropicales como la Amazonía. Según reportes internacionales, más del 94% de la deforestación global ocurre en los trópicos, donde se concentran los ecosistemas más biodiversos del planeta (2). 

Actualmente, el Perú no es ajeno a esta problemática. Datos de plataformas como Global Forest Watch muestran que la pérdida de cobertura arbórea en el país ha sido constante desde el año 2001, debido principalmente a actividades humanas como la agricultura, la tala y la expansión de infraestructura. Incluso, en los últimos años se han registrado incrementos significativos en la pérdida de bosques, lo que muestra que el problema sigue creciendo. Por ejemplo, en el año 2022 se registró la pérdida de aproximadamente 160 mil hectáreas de cobertura arbórea en el Perú, posicionando al país en el quinto lugar de naciones con más bajas de bosque primario a nivel mundial, evidenciando así la magnitud actual del problema , Asimismo, se estima que el 67% de la pérdida de cobertura arbórea en el país está directamente asociada a procesos de deforestación, principalmente por actividades humanas como la agricultura y la tala (2)(3). 

La deforestación en el Perú es especialmente grave porque presenta una situación crítica debido a la tala selectiva de especies de alto valor ecológico y comercial. Las redes de tráfico ilegal priorizan la extracción de "gigantes amazónicos" de lento crecimiento, como el Shihuahuaco (Dipteryx ferrea), el Cedro (Cedrela odorata) y la Caoba (Swietenia macrophylla) (11). Estas especies son esenciales para la estructura del bosque; por ejemplo, el Shihuahuaco puede tardar hasta 700 años en alcanzar su madurez reproductiva, y su extracción ilegal elimina importantes sumideros de carbono, liberando toneladas de CO2 a la atmósfera.(4)(12)

La importancia de esta problemática radica en sus consecuencias directas sobre el clima. La deforestación contribuye significativamente a las emisiones de gases de efecto invernadero, ya que los bosques almacenan grandes cantidades de carbono. Cuando estos son talados o quemados, ese carbono se libera en forma de CO₂, intensificando el calentamiento global (4). A nivel global, la pérdida de bosques tropicales está directamente relacionada con el incremento de la temperatura del planeta y eventos climáticos extremos. Además, la Amazonía peruana alberga una enorme diversidad biológica, considerada una de las más altas del mundo. Sin embargo, la pérdida de hábitats está provocando la disminución de especies y alteraciones en los ecosistemas. La destrucción de estos ambientes también incrementa el riesgo de enfermedades zoonóticas, ya que el contacto entre humanos y animales silvestres se vuelve más frecuente (1)(4). A nivel nacional, el problema se agrava por la ilegalidad. En el Perú, se han detectado más de 24 mil metros cúbicos de madera de origen ilegal, así como cargamentos valorizados en millones de soles, esto deja claro el impacto económico y ambiental que genera esta actividad. Un caso representativo es el ocurrido en Ucayali, donde se intervino madera ilegal valorizada en más de seis millones de soles, reflejando la alta rentabilidad de esta práctica y su impacto directo en la deforestación del país (6)(7). Esto demuestra que la deforestación no solo es un problema ecológico, sino también social y económico. 

A pesar de estos esfuerzos, el Estado enfrenta múltiples barreras para frenar esta actividad. Las Fiscalías Especializadas en Materia Ambiental (FEMA) y el OSINFOR operan a menudo con una brecha de información en tiempo real, lo que permite que la madera ilegal sea procesada o movilizada antes de que se ejecute una intervención fiscal efectiva (13). Esta falta de alertas tempranas impide que el Estado ejerza una fiscalización eficiente, resultando en pérdidas económicas y ambientales que afectan directamente la sostenibilidad del país. Por eso, implementar monitoreo acústico se vuelve vital para que las autoridades puedan actuar en tiempos mínimos de respuesta (14). 

Asimismo, el modelo de desarrollo basado en la explotación de recursos ha generado una presión constante sobre los bosques amazónicos. En muchos casos, el crecimiento económico ha sido priorizado sobre la sostenibilidad, lo que ha llevado a la degradación progresiva de los ecosistemas y la pérdida de servicios ambientales esenciales como la regulación del clima y el ciclo del agua (5). La deforestación altera procesos fundamentales como el ciclo del carbono y el equilibrio de los ecosistemas, afectando tanto a la naturaleza como a las poblaciones humanas que dependen de estos recursos para su subsistencia (8).

En respuesta a la necesidad de una solución no invasiva y tras analizar la magnitud de la problemática, se propone el desarrollo de un dispositivo tecnológico innovador diseñado para detectar posibles actividades de tala ilegal en zonas vulnerables de la Amazonía. Este sistema funcionará como un mecanismo de monitoreo inteligente que integrará un micrófono para captar los sonidos del entorno y, mediante el análisis de espectros de frecuencia y técnicas de inteligencia artificial, diferenciar sonidos asociados a motosierras, maquinaria pesada, voces humanas y otros eventos relevantes.

Por ello, el dispositivo estará basado en un microcontrolador e integrará sensores de presencia, vibración e inclinación, además de un módulo GPS para la geolocalización de eventos. Gracias a su bajo consumo energético y a la integración con una aplicación móvil, los usuarios podrán visualizar alertas, ubicación aproximada y nivel de riesgo en tiempo real. De esta manera, se busca ofrecer una solución eficiente, accesible y sostenible que contribuya a la detección temprana de actividades de tala ilegal, fortaleciendo la vigilancia forestal y apoyando la conservación de los ecosistemas amazónicos.

### Bibliografía:
1. Moran M. ODS15: Bosques, desertificación y diversidad biológica [Internet]. Desarrollo Sostenible. 26 de enero de 2024 [citado el 14 de abril de 2026]. Disponible en: https://www.un.org/sustainabledevelopment/es/biodiversity/
2. Weisse M, Goldman E, Carter S. ¿Cuánto bosque se perdió en 2022? [Internet]. Global Forest Review; 2023 [citado 19 de abril de 2026]. Disponible en: https://gfr.wri.org/es/global-tree-cover-loss-data-2022  
3. Global Forest Watch. Peru Deforestation Rates & Statistics [Internet]. Washington, D.C.: Global Forest Watch; s. f. [citado 19 de abril de 2026]. Disponible en: https://www.globalforestwatch.org/dashboards/country/PER/ 
4. Nunez C. Why deforestation matters—and what we can do to stop it [Internet]. National Geographic; 2025 [citado 19 de abril de 2026]. Disponible en: https://www.nationalgeographic.com/environment/article/deforestation
5. Quispe Alí KE. Deforestación en la Amazonía: el costo ambiental de un desarrollo sin control [Internet]. Lima: Pontificia Universidad Católica del Perú, Clima de Cambios; 2025 [citado 19 de abril de 2026]. Disponible en: https://www.pucp.edu.pe/climadecambios/noticias/deforestacion-en-la-amazonia-el-costo-ambiental-de-un-desarrollo-sin-control/ 
6. Organismo de Supervisión de los Recursos Forestales y de Fauna Silvestre. OSINFOR identificó más de 24 mil metros cúbicos de madera de origen ilegal mediante inteligencia artificial en el monitoreo satelital [Internet]. Lima: OSINFOR; 2025 [citado 19 de abril de 2026]. Disponible en: https://www.gob.pe/institucion/osinfor/noticias/1191654-osinfor-identifico-mas-de-24-mil-metros-cubicos-de-madera-de-origen-ilegal-mediante-inteligencia-artificial-e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  
7. Ministerio del Interior. Ucayali: Intervienen madera valorizada en más de seis millones de soles [Internet]. Lima: Ministerio del Interior; 2023 [citado 19 de abril de 2026]. Disponible en: https://www.gob.pe/institucion/mininter/noticias/828157-ucayali-intervienen-madera-valorizada-en-mas-de-seis-millones-de-soles
8. La Barreda Noa SD. Deforestación en la región amazónica del Perú: situación y perspectivas. M+Rev Electrón Medioambiente [Internet]. 2021 [citado el 27 de abril de 2026];22(2):20–39. Disponible en: https://dialnet.unirioja.es/servlet/articulo?codigo=8488495 
9. Servicio Nacional Forestal y de Fauna Silvestre (SERFOR). SERFOR decomisa cargamento de caoba y cedro valorizado en 80 mil soles, Lima: SERFOR; 2024 [citado 2026 Jun 3]. Disponible en: https://www.gob.pe/institucion/serfor/noticias/1053504-serfor-decomisa-cargamento-de-caoba-y-cedro-valorizado-en-80-mil-soles

---

## Versión inicial

### Diseño de un sistema IoT para la detección y disuasión de murciélagos hematófagos (Desmodus rotundus) en zonas ganaderas del Perú

En este presente proyecto de innovación, se ha decidido abordar una problemática vinculada al Objetivo de Desarrollo Sostenible 15 (ODS15): Vida y ecosistema terrestre, propuesto en la Agenda 2030. Este objetivo comprende un conjunto amplio de metas interrelacionadas que evidencian un enfoque integral orientado a la conservación de los ecosistemas terrestres y de la biodiversidad, buscando soluciones que permitan reducir los conflictos entre la actividad humana y la fauna silvestre sin alterar el equilibrio ecológico (1).

A partir de esta perspectiva, el proyecto se centrará en la interacción entre la ganadería y el murciélago hematófago Desmodus rotundus, una especie que, aunque forma parte de la biodiversidad neotropical, también representa un riesgo sanitario y productivo en zonas rurales donde existe actividad pecuaria.

Desmodus rotundus, conocido comúnmente como murciélago vampiro, es una de las tres especies de murciélagos estrictamente hematófagos y es el principal transmisor del virus de la rabia (VAR) hacia el ganado en América Latina (4). Su presencia es alta en espacios donde abundan animales domésticos y de producción, especialmente bovinos, caprinos, equinos y otros mamíferos que le sirven como fuente accesible de alimento. No obstante, el análisis de esta especie no debe conducir a su estigmatización, ya que los murciélagos, como grupo, cumplen funciones ecológicas esenciales en los ecosistemas, entre ellas el control de insectos, la dispersión de semillas y la polinización, por lo que cualquier propuesta de intervención debe considerar criterios de conservación y manejo responsable (4,5).

En Apurímac, un estudio reportó que el índice general de mordeduras por D. rotundus en animales de producción aumentó de 13.87% en 2021 a 15.69% en 2022; en bovinos, dicho índice pasó de 11.11% a 12.05%, mientras que en caprinos ascendió de 27.59% a 39.84% (7). Estos datos muestran que la presión de ataque sobre los animales no es aislada ni marginal, sino persistente y, en algunos casos, creciente. De manera complementaria, investigaciones recientes en Cajamarca identificaron factores de riesgo asociados a la rabia bovina y modeló su potencial expansión hasta el 78,12% de la región, lo que refuerza la necesidad de vigilancia territorial y prevención focalizada (3, 7). El principal riesgo derivado de estas mordeduras no radica únicamente en la pérdida de sangre o en el debilitamiento progresivo del animal, sino en la posibilidad de transmisión de la rabia silvestre, una enfermedad viral que afecta el sistema nervioso central y que es prácticamente mortal una vez que aparecen los síntomas clínicos (2).  

Desde lo económico, la rabia transmitida por Desmodus rotundus genera pérdidas por mortalidad directa, reducción en la producción de carne y leche, así como por los costos de vacunación y control. A nivel regional, la literatura reporta un promedio de 450 brotes anuales de rabia bovina transmitida por vampiros en América Latina entre 1970 y 2023, ubicando a Brasil, Colombia, Perú y México entre los países más afectados (4). En propiedades ganaderas, las pérdidas anuales pueden alcanzar al menos USD 5,000 por predio, mientras que el gasto en vacunación puede oscilar entre USD 2 y USD 1,437, con un promedio anual de USD 148 por propiedad, lo que demuestra que incluso la prevención representa una carga económica sostenida (4). Es importante precisar que el término “predio” hace referencia a una unidad productiva agropecuaria, cuyo tamaño no es fijo, ya que puede variar dependiendo de la extensión del terreno y la cantidad de ganado presente. En el caso peruano, el Censo Nacional Agropecuario 2012 estimó la existencia de 2,260,973 unidades agropecuarias (11), lo que permite dimensionar el alcance potencial del problema. A ello se suman evidencias recientes que confirman la vigencia de la rabia silvestre hasta 2023, así como su impacto económico y sanitario continuo sobre el sector ganadero y las comunidades rurales.

Frente a esta situación, se han planteado soluciones que van desde el uso de mallas en los ganados cerrados hasta el ataque directo a las colonias de estos murciélagos mediante el uso de gases venenosos, insecticidas como el dicloro difenil tricloroetano (DDT), dieldrín y malathion así como explosivos e incendios que provocan daños colaterales a la flora y fauna del lugar afectado (6). A estas intervenciones se le suma el uso de pomadas vampiricidas (anticoagulante en un vehículo como la vaselina), las cuales se les aplica usualmente en los dorsos de los Desmodus rotundus para luego liberarlos y aprovechar su conducta de acicalamiento individual y social a fin de que el veneno sea ingerido por múltiples vampiros (generalmente 15 por murciélago tratado) y provoque su muerte, sin embargo, aquellos que son beneficiosos para el ambiente también terminan siendo víctimas de este método ante la desinformación sobre diferenciación de especies (6,8). Si bien el uso de anticoagulantes ha demostrado alta eficacia para inducir la mortalidad en individuos de Desmodus rotundus, la evidencia científica actual no confirma su efectividad para reducir la transmisión del virus de la rabia a nivel poblacional. Por el contrario, diversos estudios sugieren que la perturbación de las colonias puede incrementar la dispersión del virus, lo que limita la eficacia de esta estrategia como medida de control sanitario (10). 

En respuesta a la necesidad de una solución no invasiva, y tras analizar la magnitud de la problemática, se propone el desarrollo de un dispositivo tecnológico innovador diseñado para detectar la presencia de Desmodus rotundus en zonas ganaderas. Este sistema funcionará como un mecanismo de monitoreo y disuasión inteligente que integrará un micrófono para captar los sonidos del ambiente y, mediante las señales, diferenciar al murciélago de otros animales. Una vez detectada su presencia, el dispositivo activará la emisión de sonidos específicos y la proyección de luces de alta intensidad con el propósito de ahuyentarlo sin ocasionar daño. 

Asimismo, el dispositivo estará basado en un sistema de tecnología basado en un microcontrolador y sensores de presencia junto a un sensor de luz que permitirá su implementación en zonas rurales mediante un bajo consumo energético y una aplicación relativamente accesible, donde los registros de ataques y alarmas se puedan ver mediante una app de celular. De esta manera, se busca ofrecer una solución eficiente, sostenible y respetuosa con el equilibrio ecológico, capaz de reducir los ataques al ganado sin recurrir a métodos extremos, promoviendo así una convivencia más armónica entre la actividad ganadera y la conservación del ecosistema.

### Bibliografía:
1. Moran M. ODS15: Bosques, desertificación y diversidad biológica [Internet]. Desarrollo Sostenible. 2015 [citado el 14 de abril de 2026]. Disponible en: https://www.un.org/sustainabledevelopment/es/biodiversity/ 
2. Rabia [Internet]. Who.int. 5 de junio de 2024 [citado el 14 de abril de 2026]. Disponible en: https://www.who.int/es/news-room/fact-sheets/detail/rabies  
3. Vista de Factores de riesgo asociados a casos de rabia bovina y potencial distribución hacia zonas vulnerables en Cajamarca, Perú [Internet]. Edicionescervantes.com. 2025 [citado el 14 de abril de 2026]. Disponible en: https://www.censa.edicionescervantes.com/index.php/RSA/article/view/1446/2739 
4. Soler-Tovar D, Escobar LE. Rabies transmitted from vampires to cattle: An overview. PLoS One [Internet]. 13 de enero de 2025;20(1):e0317214. Disponible en: http://dx.doi.org/10.1371/journal.pone.0317214 
5. Ramírez-Fráncel LA, García-Herrera LV, Losada-Prado S, Reinoso-Flórez G, Sánchez-Hernández A, Estrada-Villegas S, et al. Bats and their vital ecosystem services: a global review. Integr Zool [Internet]. 08 de junio de 2021;17(1):2–23. Disponible en: http://dx.doi.org/10.1111/1749-4877.12552 
6. Aguilar-Setién A, Olave-Leyva JI, Hurtado-Mendoza E, Acuña-Ruiz M, Aréchiga-Ceballos N. Crónica sobre los métodos de control del murciélago vampiro común (Desmodus rotundus). 2026 [citado el 14 de abril de 2026]; Disponible en: https://www.researchgate.net/profile/Alvaro-Aguilar-Setien-2/publication/400312392_CRONICA_SOBRE_LOS_METODOS_DE_CONTROL_DEL_VAMPIRO_COMUN_Desmodus_rotundus/links/698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 
7. Cayllahua AC. Análisis de la dinámica poblacional del murciélago hematófago (Desmodus rotundus) e impacto en animales de producción en el Departamento de Apurímac, periodo 2021-2022 [Internet]. Edu.pe. 2025 [citado el 14 de abril de 2026]. Disponible en: https://repositorio.unamba.edu.pe/server/api/core/bitstreams/366ac8ea-2a93-427d-9026-0f8805b31209/content 
8. Viana M, Benavides JA, Broos A, Ibañez Loayza D, Niño R, Bone J, et al. Effects of culling vampire bats on the spatial spread and spillover of rabies virus. Sci Adv [Internet]. 2023;9(10):eadd7437. Disponible en: http://dx.doi.org/10.1126/sciadv.add7437
9. Van de Vuurst P, Díaz MM, Rodríguez-San Pedro A, Allendes JL, Brown N, Gutiérrez JD, et al. A database of common vampire bat reports. Sci Data [Internet]. 2022 [citado el 21 de abril de 2026];9(1):57. Disponible en: https://www.nature.com/articles/s41597-022-01140-9  
10. Ávila-Vargas L, Soler-Tovar D, Dong Q, Escobar LE. Anticoagulants for the Control of the Common Vampire Bat (Desmodus rotundus). Zoonoses Public Health [Internet]. 2025;72(2):101–16. Disponible en: http://dx.doi.org/10.1111/zph.13196  
11. Consultar información de los censos realizados por el INEI [Internet]. Gob.pe. [citado el 21 de abril de 2026]. Disponible en: https://www.gob.pe/36487-consultar-informacion-de-los-censos-realizados-por-el-inei-censos-nacionales-agropecuario

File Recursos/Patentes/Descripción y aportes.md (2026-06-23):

# Patentes - Proyecto YuraGuard

## Patente 1: US2025046333A1
- **Título:** Sistema de detección de eventos sonoros acústicos
- **Código:** US2025046333A1
- **Año:** 2025
- **Inventores:** GM, LAD, RMH
- **Resumen:** La invención describe un sistema para la detección automática de eventos acústicos mediante la captura y procesamiento de señales de sonido. El sistema analiza características acústicas específicas para identificar eventos de interés dentro del entorno monitoreado, permitiendo una detección temprana y precisa mediante técnicas de procesamiento digital de señales y clasificación automatizada. Está diseñado para operar de forma continua y generar alertas cuando se detectan patrones acústicos previamente definidos.
- **Aporte al proyecto:**
  - Valida el uso de análisis de eventos acústicos para la detección automática de actividades anómalas.
  - Respaldar la extracción de características de audio mediante procesamiento digital de señales.
  - Justifica la implementación de algoritmos de clasificación para reconocer sonidos específicos, como motosierras o actividades de tala.
  - Refuerza la viabilidad del monitoreo acústico continuo en entornos remotos.
  - Proporciona evidencia del interés industrial reciente en sistemas inteligentes de detección basados en audio.
- **Link:** https://worldwide.espacenet.com/patent/search/family/087348851/publication/US2025046333A1?q=US20250046333A1

---
  
## Patente 2: US2025104698A1
- **Título:** Detección de tipo de audio
- **Código:** US2025104698A1
- **Año:** 2025
- **Inventores:** KK, GC, NV
- **Resumen:** El procesamiento basado en inteligencia artificial se utiliza para clasificar la información de audio recibida de una unidad de entrada de audio. Un circuito procesador identifica características de la información de audio del micrófono y utiliza algoritmos de aprendizaje automático para analizar dichas características y determinar si incluye indicios de un evento anómalo. También puede usar algoritmos de aprendizaje profundo basados en redes neuronales para clasificar el audio como indicativo de un tipo de evento específico.
- **Aporte al proyecto:**
  - Respaldar el uso de IA y Edge Impulse para clasificación de audio
  - Valida el enfoque de FFT + Machine Learning para detección de patrones
  - Justifica el procesamiento local (TinyML) en el ESP32-S3
  - Demuestra la efectividad de redes neuronales para clasificación de sonidos ambientales
- **Link:** https://worldwide.espacenet.com/patent/search/family/067618015/publication/US2025104698A1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

---

## Patente 3: CN102393986A
- **Título:** Método, dispositivo y sistema de detección de tala ilegal basado en la diferenciación de frecuencias de audio
- **Código:** CN102393986A
- **Año:** 2012
- **Inventores:** Hu X, Tang Y, Mo B, Wang Y, Xiong L, Han P, et al.
- **Resumen:** La invención proporciona un método, un dispositivo y un sistema para la detección de tala ilegal basados en la diferenciación de frecuencias de audio. Este método permite identificar actividades de tala ilegal en cualquier momento mediante la simple recolección de sonidos del entorno, presentando una baja complejidad técnica, así como costos reducidos de desarrollo y uso, además de una alta eficiencia en la detección y ejecución.
- **Aporte al proyecto:** 
  - Demuestra la viabilidad de detectar tala ilegal mediante análisis de frecuencias de audio
  - Proporciona una base técnica para el uso de microcontroladores de bajo costo
  - Valida el enfoque de monitoreo acústico continuo en tiempo real
  - Muestra potencial de aplicación industrial y escalabilidad
- **Link:** https://worldwide.espacenet.com/patent/search/family/045861294/publication/CN102393986A?q=CN102393986A

---

## Patente 4: US20240054154A1
- **Título:** Sistema dinámico de firmas acústicas con fusión de sensores para la tala ilegal en la selva tropical
- **Código:** US20240054154A1
- **Año:** 2024
- **Inventores:** WUJ, DMA, A-U-AF, LW, SW
- **Resumen:** Las implementaciones descritas detectan una perturbación humana a partir de datos de sensores transmitidos desde uno o más sensores dentro de una red de sensores; procesan la perturbación humana detectada para determinar una probabilidad de un evento de motosierra (leve o intenso) y un tiempo estimado de anticipación; y determinan, para los sensores vecinos, una probabilidad de cambio de estado hacia la perturbación humana o hacia el evento de motosierra en otras áreas.
- **Aporte al proyecto:**
  - Valida el uso de fusión de sensores (múltiples sensores trabajando juntos)
  - Demuestra la importancia de las redes de sensores para cobertura amplia
  - Proporciona metodología para calcular probabilidades de eventos
  - Justifica el uso de radar, micrófono y sensor de vibración en YuraGuard
- **Link:** https://worldwide.espacenet.com/patent/search/family/082259630/publication/US2024054154A1?q=US20240054154A1

---

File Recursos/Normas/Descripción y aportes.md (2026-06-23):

# Normas Técnicas - Proyecto YuraGuard

## Norma Técnica 1: IEC 60529 (Grados de Protección IP)
- **Descripción:** Norma internacional que establece los grados de protección de las envolventes eléctricas frente al ingreso de polvo, agua y contacto con partes peligrosas.
- **Aporte al proyecto:** Permite seleccionar una carcasa adecuada para proteger los componentes electrónicos de YuraGuard en ambientes forestales expuestos a lluvia, humedad y partículas de polvo.

---

## Norma Técnica 2: ISO 14001:2015 (Sistema de Gestión Ambiental)
- **Descripción:** Norma internacional que define los requisitos para implementar un sistema de gestión ambiental orientado a la protección del medio ambiente y la mejora continua.
- **Aporte al proyecto:** Brinda lineamientos para que YuraGuard contribuya a la vigilancia ambiental y a la reducción de impactos asociados a la deforestación, alineándose con principios de sostenibilidad.

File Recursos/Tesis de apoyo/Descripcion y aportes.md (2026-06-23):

# Descripción y Aportes de Tesis de Apoyo

## Tesis 1: Sistema de monitoreo ambiental basado en IoT para zonas rurales- PUCP
- **Universidad:** Pontificia Universidad Católica del Perú (PUCP)
- **Año:** 2018
- **Autores:** Huayap M, de Jesús DG
- **Descripción:** Propone un sistema de monitoreo ambiental basado en Internet de las Cosas (IoT), orientado a la supervisión de condiciones en zonas de difícil acceso. El sistema emplea sensores conectados a microcontroladores para la recolección de datos en tiempo real, los cuales son transmitidos a una plataforma digital para su visualización y análisis remoto, permitiendo el monitoreo continuo de variables ambientales sin intervención directa en campo.
- **Aporte al proyecto:**
  - Permite identificar una arquitectura base de IoT aplicable al sistema YuraGuard
  - Proporciona un modelo de integración de sensores, microcontroladores y comunicación inalámbrica
  - Demuestra la viabilidad del monitoreo remoto en zonas forestales de difícil acceso
  - Valida el uso de plataformas digitales para visualización y análisis de datos ambientales
- **Link:** https://tesis.pucp.edu.pe/items/a42150fb-3ed8-4742-96fc-1b59134b42e8

---

## Tesis 2: Detección de eventos mediante análisis de señales acústicas - UNMSM
- **Universidad:** Universidad Nacional Mayor de San Marcos (UNMSM)
- **Año:** 2016
- **Autores:** Dora CP
- **Descripción:** Propone un sistema de monitoreo acústico basado en sensores de sonido, enfocado en la detección de eventos ambientales mediante el análisis de señales acústicas. El sistema utiliza micrófonos conectados a microcontroladores para capturar audio del entorno, el cual es procesado mediante técnicas de análisis de frecuencia para identificar patrones asociados a actividad humana o alteraciones en el ambiente.
- **Aporte al proyecto:**
  - Sirve como base para el módulo de detección acústica del sistema YuraGuard
  - Valida el uso de sensores de audio y procesamiento de señales para identificar eventos
  - Demuestra la efectividad del análisis de frecuencia para detectar motosierras o intervención humana
  - Proporciona metodología para el procesamiento de señales acústicas con microcontroladores
- **Link:** https://cybertesis.unmsm.edu.pe/item/0ac3503c-710e-424a-a4f8-16cafef3b110

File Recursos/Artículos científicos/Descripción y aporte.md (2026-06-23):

# Descripción y Aportes de Artículos Científicos

## Artículo 1: Sistemas de Telemetría basados en IoT
- **Autores:** Cholilurrohman, Indah Sulistyowati y Arief Wicaksono
- **Año:** 2023
- **Resumen:** El estudio presenta sistemas de telemetría basados en tecnología IoT que permiten la recolección y transmisión de datos en tiempo real desde múltiples sensores distribuidos en campo. Estos sistemas utilizan microcontroladores para procesar la información y enviarla a plataformas de monitoreo remoto, facilitando la supervisión continua de variables ambientales en zonas de difícil acceso.
- **Aporte:** Sincronización eficiente entre captura de datos y transmisión para evitar latencia.
- **Limitaciones:** El rendimiento del sistema depende de la disponibilidad y calidad de la red, lo que puede generar retrasos o pérdida de información en zonas rurales o con baja conectividad.
- **Link:** https://jurnal.unmer.ac.id/index.php/jeemcs/article/view/9945/pdf

---

## Artículo 2: Sistema de Monitoreo Acústico basado en IoT
- **Autores:** Juan Jose Saldana-Barrios, Edwil Aguilar, Wing Ng y Rodert Orocú
- **Año:** 2023
- **Resumen:** El estudio presenta un sistema basado en tecnología IoT que utiliza sensores acústicos para el monitoreo y análisis de sonido en tiempo real. El sistema emplea micrófonos conectados a microcontroladores para capturar señales del entorno, las cuales son procesadas para identificar variaciones en los niveles de ruido y posibles eventos anómalos en el ambiente.
- **Aporte:** Demuestra la efectividad del uso de sensores acústicos para la detección de eventos en tiempo real, proporcionando señales claras que pueden ser procesadas por microcontroladores para identificar patrones de sonido relevantes.
- **Limitaciones:** La precisión del sistema puede verse afectada por factores ambientales como el viento, la lluvia o ruidos externos, por lo que es necesario implementar protección física y calibración adecuada del sensor.
- **Link:** https://pmc.ncbi.nlm.nih.gov/articles/PMC10675386/

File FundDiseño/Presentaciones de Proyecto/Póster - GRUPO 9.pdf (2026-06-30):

Pérdida de
cobertura arbórea
en Perú (2022)¹

Radar mm Wave (presencia humana)

# MPU6050 (vibración / inclinación) Investigación del problema

Selección de sensores
y tecnologías

Diseño del
prototipo

Pruebas de
campo

Análisis de datos y
generación de alertas

MPU6050

18650 Li-Ion (3.7 V)

Función

Procesamiento embebido
y ejecución del modelo IA

Obtención de
coordenadas del evento

De la pérdida
forestal en Perú
asociada a
deforestación²

## 4. PROPUESTA DE INNOVACIÓN

## 1.INTRODUCCIÓN GENERAL

# YYUURRAAGGUUAARRDD

La deforestación en la Amazonía peruana amenaza la biodiversidad y acelera el cambio climático. YuraGuard propone un sistema IoT con sensores e inteligencia artificial para detectar de forma temprana la tala ilegal en zonas remotas del país.

La deforestación
incrementa las emisiones
de gases de efecto
invernadero y el riesgo de pérdida de biodiversidad.

## 2. PROBLEMÁTICA

FUENTE : ¹Global Forest Watch (2022),

### ²MINAM(2024 )

Tala ilegal en zonas de difícil acceso. Escasa presencia de personal de vigilancia.
Respuesta tardía de las autoridades. Pérdida de biodiversidad y servicios ecosistémicos.
Limitada disponibilidad de información en tiempo real.

## 3. OBJETIVOS

Objetivo general
Diseñar un sistema
inteligente de monitoreo
para detectar
tempranamente
actividades relacionadas
con tala ilegal en la
Amazonía peruana.

Objetivos específicos
Detectar sonidos de motosierras y otras actividades mediante análisis acústico. Identificar presencia humana cercana. Detectar vibraciones e inclinaciones anómalas del árbol.
Registrar ubicación GPS del evento. Enviar alertas remotas al usuario.

YuraGuard integra sensores acústicos, de presencia, vibración y localización, junto con un sistema embebido de bajo consumo y algoritmos de inteligencia artificial, para detectar y alertar sobre posibles eventos de tala ilegal en tiempo real.

Micrófono (audio ambiental)

## Beneficios esperados

Detección temprana + Protección de bosques + Mejora de vigilancia + Apoyo a MINAM y SERFOR

## 5. METODOLOGÍA DE INVESTIGACIÓN

Audio ambiental | FFTT

MODELO IA
(Edge Impulse)

Clasificación:
motosierras / otros

Validación con sensores
(presencia + vibración +
GPS)

Alerta al usuario
(aplicación móvil

## 6.COMPONENTES PRINCIPALES

MODELO

MAX9814

mmWave

ESP32-S3-WROOM-1

NEO - 6M

NRF24LO01 +
PA + LNA

Captura de audio ambiental

Detección de presencia
y movimiento cercano

Detección de vibracion
e inclinación del arbol

Comunicación
inalámbrica de largo
alcance

Alimentación de largo
tiempo

Figura 1 . Metologia general del sistema YuraGuard
FUENTE : Elaboración propia

Figura 2 . Componentes principales del sistema F UENTE: Elaboracion propia

Martha Sofia Medina Rojas, Aldair Castillo Quispe, Xiomara Quispe Casio, Angel Gabriel Valverde Paucarmayta , Anderson Aldhair Bruno Sanchez Fundamentos de diseño 2026-1 Ingeniería Ambiental, Ingeniería Industrial e Ingeniería Informática

ESP32-S3 (procesamiento local + IA)

160 000 ha

60%

## 9. CONCLUSIONES, RECOMENDACIONES Y LECCIONES APRENDIDAS

## Conclusiones

## Se diseñó un sistema IoT capaz de integrar múltiples sensores para el monitoreo

forestal.

## Se espera que el análisis multisensor y el uso de IA reduzcan falsas alarmas frente al

ruido ambiental.

## YuraGuard podría contribuir a la detección

temprana de tala ilegal en zonas remotas, apoyando a MINAM y SERFOR.

## Recomendaciones

### Realizar pruebas de campo en

condiciones reales (lluvia, viento, motosierras reales).

### Optimizar el modelo de IA con más muestras de audio

locales.

### Evaluar el uso de LoRaWAN para mayor alcance y

cobertura en la Amazonía.

### Mejorar la protección de la carcasa ante humedad y

fauna.

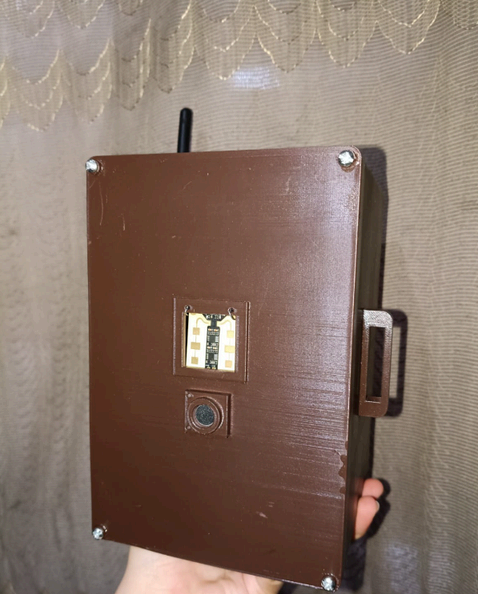
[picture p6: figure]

## Lecciones aprendidas

### La integración de múltiples sensores mejora la confiabilidad

del sistema.

### La selección adecuada de componentes influye directamente en la

autonomía.

### El diseño mecánico debe

priorizar protección,

### instalación y

mantenimiento.

## 8.Rendimiento estimado

## Parámetros de desempeño esperados

## Parámetro

### Alcance de detección Autonomía energética

## Tiempo de respuesta

## Precisión esperada

## Valor estimado

### Hasta 100 m 1 mes

< 5 s

### Alta

## Descripción

## Bajo condiciones ambientales favorables

### Según consumo estimado del sistema Desde detección hasta alerta

### Basada en validación multisensor

## Figura 3 . YURAGUARD

### FUENTE: ELABORACION PROPIA

## 10. REFERENCIAS

1.Global Forest Watch. Peru deforestation rates & statistics. Washington DC; World Resources Institute; 2022. 2.Ministerio del Ambiente (MINAM). Estrategia Nacional ante el Cambio Climático al 2050. Lima: MINAM; 2024. 3.OSINFOR. OSINFOR identificó más de 24 mil m³ de madera de origen ilegal mediante IA. Lima: OSINFOR; 2025. 4.Rainforest Connection. Guardian 3: Acoustic monitoring device. 2023.
5.Open Acoustic Devices. AudioMoth user guide. 2023

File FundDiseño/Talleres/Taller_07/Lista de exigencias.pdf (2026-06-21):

LISTA DE EXIGENCIA

Páginas: 5

Edición: Rev. 3

PROYECTO | YURAGUARD

Fecha: 29/04/26

Revisado:

CLIENTE | UNIVERSIDAD PERUANA CAYETANO HEREDIA | Elaborado: M.M, A.C, A.V, A.B, X.Q
Fechas (Cambios) | Deseo o exigencia | Descripción | Responsable:
27/04/26 | E | Función Principal: El sistema deberá vigilar un radio acústico objetivo de hasta 100 m en condiciones favorables para reconocer sonidos asociados a tala ilegal, como motosierras, caída de árboles y maquinaria pesada. La detección se realizará mediante captura de audio, análisis de frecuencias con Transformada Rápida de Fourier (FFT) y clasificación con IA entrenada en Edge Impulse. Al confirmar una situación de riesgo, el sistema enviará una alerta a la aplicación móvil con ubicación GPS y estado del evento. | M.M
29/04/26 | E | Geometría: El dispositivo deberá colocarse en el tronco de un árbol, preferentemente entre 2,5 m y 3,5 m de altura, con el fin de dificultar su acceso y evitar que personas lo retiren o manipulen, sin causar daño al árbol. La caja no deberá ser muy grande, máximo 25cm x 18cm x 12cm pero sí contar con espacio suficiente para alojar el microcontrolador, batería, regulador, GPS, antena y sensores. Se sujetará mediante correas o abrazaderas. | A.C
29/04/26 | E | Cinemática: El sistema deberá tomar pequeñas muestras de audio de 1 a 2 segundos para reconocer patrones de motosierra, voz humana o caída de árboles. El radar detectará presencia cercana humana.. El sensor de vibración detectará cambios de aceleración e inclinación del árbol para identificar vibraciones o movimientos anómalos asociados al corte. | A.B

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

a

nim

ale

s, llu

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
al. 29/04/26 | E | Electrónico (Hardware): Se usará un microcontrolador con capacidad de TinyLM para el uso de IA. El prototipo incluirá un micrófono para captar audios, un radar para presencia cercana, sensor de vibración e inclinación, dispositivo para localización, batería recargable con BMS, regulador de voltaje y, según disponibilidad, un módulo para comunicación. Las conexiones deberán estar soldadas o aseguradas con conectores resistentes. | A.C, M.M 29/04/26 | E | Software: El programa deberá leer el audio, aplicar FFT para obtener los espectros, clasificar con Edge Impulse y revisar los datos del radar, sensor de vibración y GPS. La aplicación móvil deberá mostrar la ubicación, tipo de alerta, nivel de riesgo, batería y estado del dispositivo. Los umbrales podrán ajustarse después de las pruebas. | A.C, M.M 27/04/26 | E | Comunicaciones: El sistema deberá enviar alertas a una aplicación móvil o base de datos. Si no hay internet, se recomienda usar LoRa hacia una estación cercana. Bluetooth o Wi-fi se usará solo para configuración o pruebas. Si no hay señal, el sistema guardará los eventos hasta poder enviarlos. | A.C 27/04/26 | E | Seguridad: El dispositivo deberá protegerse contra lluvia, humedad, golpes y manipulación no autorizada. La caja deberá tener seguros o tornillos. La instalación no deberá dañar el árbol ni poner en riesgo a personas o animales. La batería deberá tener protección contra sobrecarga, cortocircuito y descarga profunda. | A.V 29/04/26 | E | Ergonomía: El equipo deberá ser fácil de transportar e instalar por una o dos personas. No deberá pesar mucho. La | X.Q

a

plic

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
e lo más importante: ubicación, tipo de alerta y nivel de riesgo. El mantenimiento debe ser fácil de entender para usuarios no especializados. 27/04/26 | E | Fabricación: El prototipo deberá fabricarse con componentes accesibles en Lima o mediante proveedores comunes: microcontrolador, micrófono, radar, sensor de vibración, gps, batería, caja estanca, cables, conectores y módulo de comunicación. La estructura debe permitir ensamblaje manual, reparación rápida y reemplazo independiente de sensores. Se priorizará un diseño modular para facilitar pruebas, escalado y una posible protección de propiedad intelectual | M.M 29/04/26 | E | Control de calidad: El sistema deberá probarse en laboratorio. Se evaluará si detecta motosierra, voz humana, presencia humana, vibración del árbol y ubicación. La IA deberá de ser muy cercana a lo exacto. | A.B 29/04/26 | E | Montaje: La instalación deberá realizarse en árboles estratégicos cercanos a rutas, bordes de bosque o zonas de riesgo. El micrófono debe quedar protegido de lluvia directa y viento, pero sin obstrucción acústica. El radar deberá apuntar hacia zonas de paso probable, entendiendo que no cubre un radio completo. El GPS deberá ubicarse con la mayor visibilidad posible al cielo; bajo dosel cerrado se aceptará una precisión reducida y se priorizará la ubicación aproximada. | A.V , M.M , A.C 29/04/26 | E | Transporte: El equipo deberá trasladarse en una caja rígida o mochila técnica. La batería debe ir protegida contra golpes y cortocircuitos. Deberá incluir correas, batería cargada, manual breve y | A.V

| | conectores de repuesto.
29/04/26 | D | Uso: El dispositivo se usará en zonas amazónicas con humedad alta, lluvia frecuente, presencia de animales, vegetación densa y baja conectividad. El alcance real de audio puede disminuir por lluvia, viento, relieve, densidad del bosque y orientación del micrófono. Por ello, los 100 m de escucha de motosierras deben considerarse un alcance objetivo en condiciones favorables y validarse con pruebas. El sistema no reemplaza la vigilancia humana, sino que funciona como alerta temprana. | A.V
29/04/26 | E | Mantenimiento: Se debería de limpiar la entrada del micrófono, revisar la batería, los sellos, las correas, la comunicación y los registros. Si aparecen falsas alarmas, se ajustará o actualizará el modelo de IA. | A.V
29/04/26 | D | Costos: El prototipo deberá mantenerse accesible para un proyecto universitario. El costo estimado por unidad será de S/ 300 a S/600, según la batería, carcasa y módulo de comunicación. El uso de Edge Impulse en versión gratuita puede ayudar a reducir costos de software durante la etapa de prototipo. | A.V , A.B
27/04/26 | E | Plazos: El proyecto dará inicio el día 28 de abril y terminará el 29 de junio. | M.M

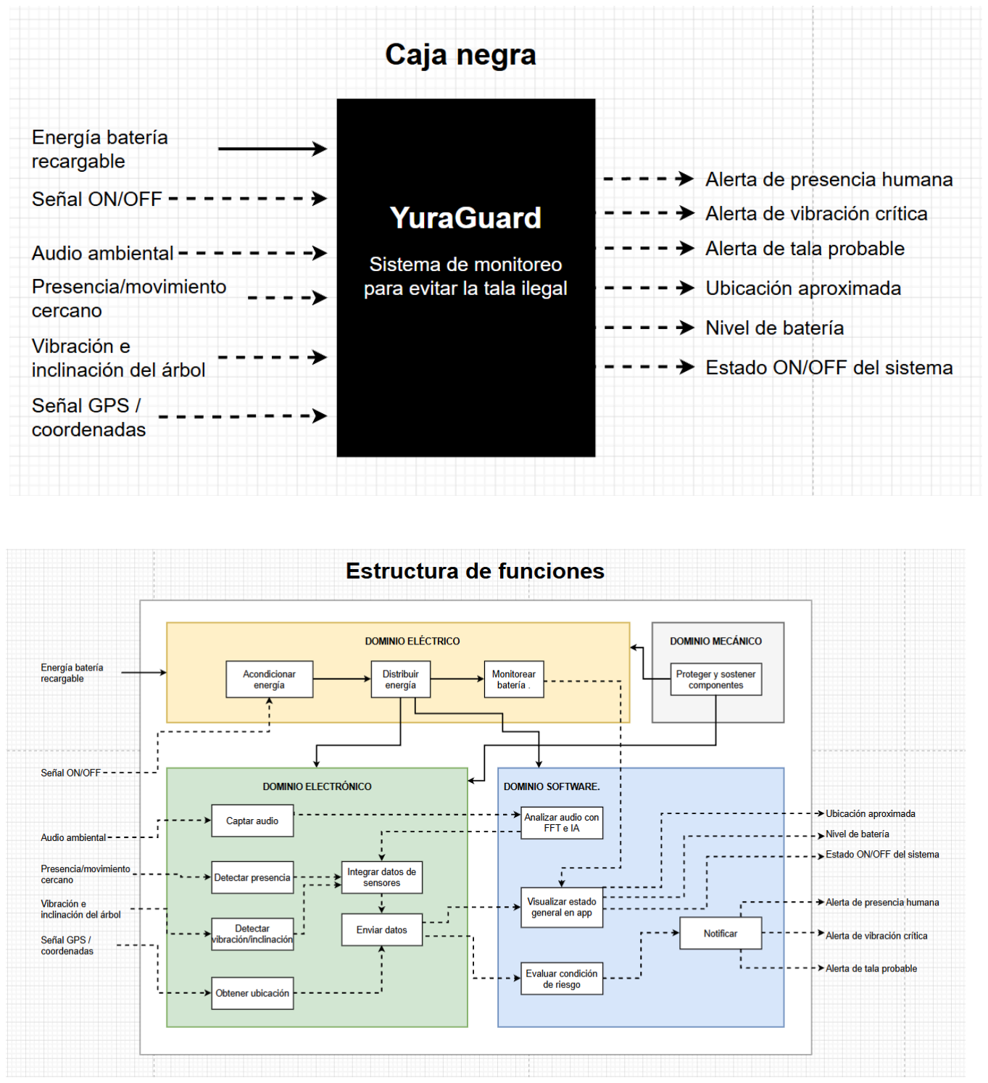
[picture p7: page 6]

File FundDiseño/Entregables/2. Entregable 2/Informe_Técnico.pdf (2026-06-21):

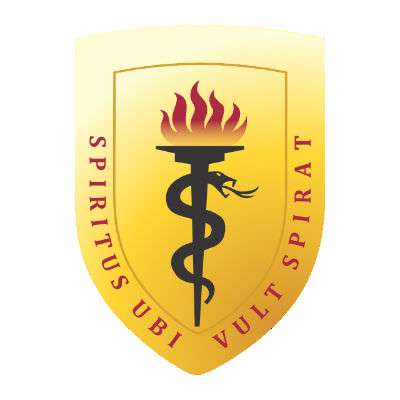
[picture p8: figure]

## UNIVERSIDAD PERUANA CAYETANO HEREDIA

### FACULTAD DE CIENCIAS E INGENIERÍA (FACI)

### INFORME TÉCNICO DEL PROYECTO

### Grupo 9

## Integrantes:

- Martha Sofía Medina Rojas
- Aldair Castillo Quispe
- Melani Xiomara Quispe Casio
- Angel Gabriel Valverde Paucarmayta
- Anderson Aldhair Bruno Sanchez

### Jefes de práctica:

- Harry Anderson Rivera Tito
- Renzo José Chan Ríos
- Julissa Elvira Venancio Huerta
- Cristhian Gustavo Jacinto Calderón

## ÍNDICE:

## Entregable 2: Informe Técnico del Proyecto

### 1. Introducción

Este proyecto de innovación aborda una problemática relacionada con el Objetivo de Desarrollo Sostenible 15 (ODS15): Vida y ecosistema terrestre, propuesto en la Agenda 2030. Este objetivo incluye varias metas relacionadas que evidencian un enfoque integral orientado a la conservación de los ecosistemas terrestres y de la biodiversidad, buscando soluciones que permitan reducir los conflictos entre la actividad humana y la fauna silvestre sin alterar el equilibrio ecológico (1).

En este contexto, el proyecto se alinea con los objetivos estratégicos del Estado peruano para la protección del patrimonio forestal nacional. El sistema funcionará como herramienta para entidades como el Ministerio del Ambiente (MINAM) y el Servicio Nacional Forestal y de Fauna Silvestre (SERFOR), Su propósito es mejorar la vigilancia en zonas críticas donde hay poco personal, lo que permitiría obtener datos más precisos para la toma de decisiones informadas y la preservación de la biodiversidad en territorios de difícil acceso(9)(10)..

### 2. Problemática

La deforestación se ha convertido en una de las amenazas ambientales más críticas a nivel mundial, especialmente en regiones tropicales como la Amazonía. Según reportes internacionales, más del 94% de la deforestación global ocurre en los trópicos, donde se concentran los ecosistemas más biodiversos del planeta (2).

Actualmente, el Perú no es ajeno a esta problemática. Datos de plataformas como Global Forest Watch muestran que la pérdida de cobertura arbórea en el país ha sido constante desde el año 2001, debido principalmente a actividades humanas como la agricultura, la tala y la expansión de infraestructura. Incluso, en los últimos años se han registrado incrementos significativos en la pérdida de bosques, lo que muestra que el problema sigue creciendo. Por ejemplo, en el año 2022 se registró la pérdida de aproximadamente 160 mil hectáreas de cobertura arbórea en el Perú, posicionando al país en el quinto lugar de naciones con más bajas de bosque primario a nivel mundial, evidenciando así la magnitud actual del problema , Asimismo, se estima que el 67% de la pérdida de cobertura arbórea en el país está directamente asociada a procesos de deforestación, principalmente por actividades humanas como la agricultura y la tala (2)(3).

La deforestación en el Perú es especialmente grave porque presenta una situación crítica debido a la tala selectiva de especies de alto valor ecológico y comercial. Las redes de tráfico ilegal priorizan la extracción de "gigantes amazónicos" de lento crecimiento, como el Shihuahuaco (Dipteryx ferrea), el Cedro (Cedrela odorata) y la Caoba (Swietenia macrophylla) (11). Estas especies son esenciales para la estructura del bosque; por ejemplo, el Shihuahuaco puede tardar hasta 700 años en alcanzar su madurez reproductiva, y su extracción ilegal elimina importantes sumideros de carbono, liberando toneladas de CO2 a la atmósfera.(4)(12)
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

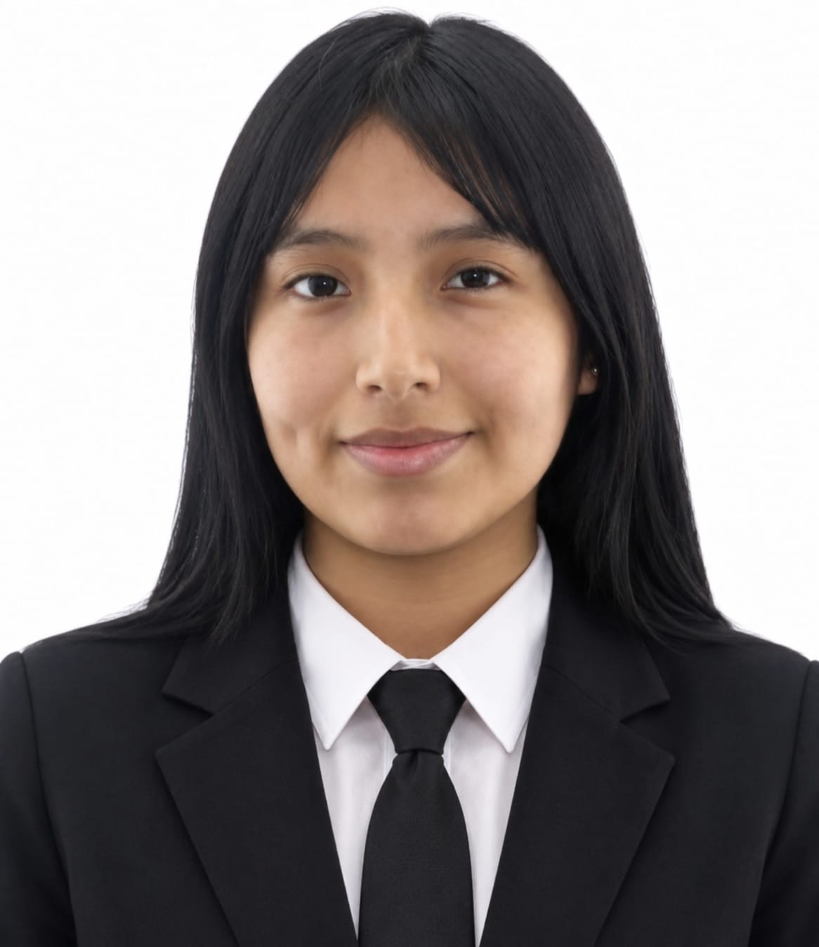
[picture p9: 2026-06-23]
Recursos/Imágenes/Melani Xiomara Quispe Casio.jpeg

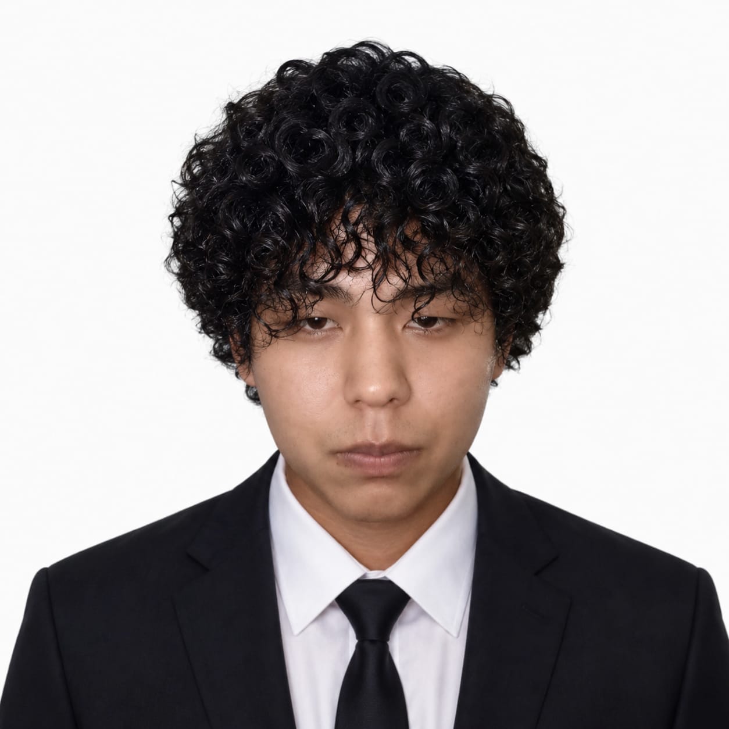
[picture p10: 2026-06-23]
Recursos/Imágenes/Aldair Castillo Quispe.jpeg

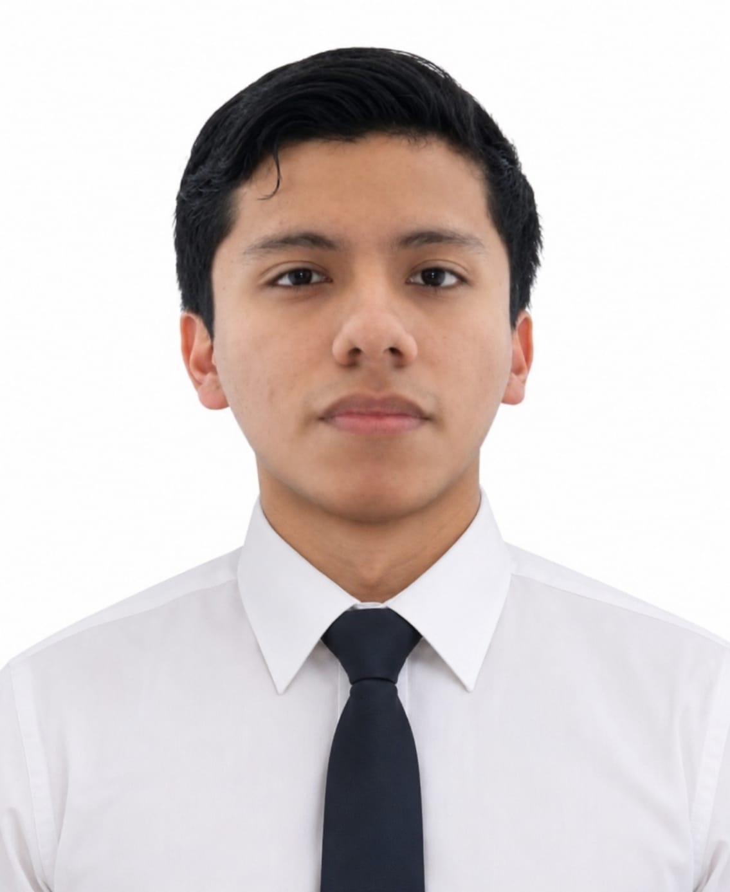
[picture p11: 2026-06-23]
Recursos/Imágenes/Angel Valverde Paucarmayta.jpeg

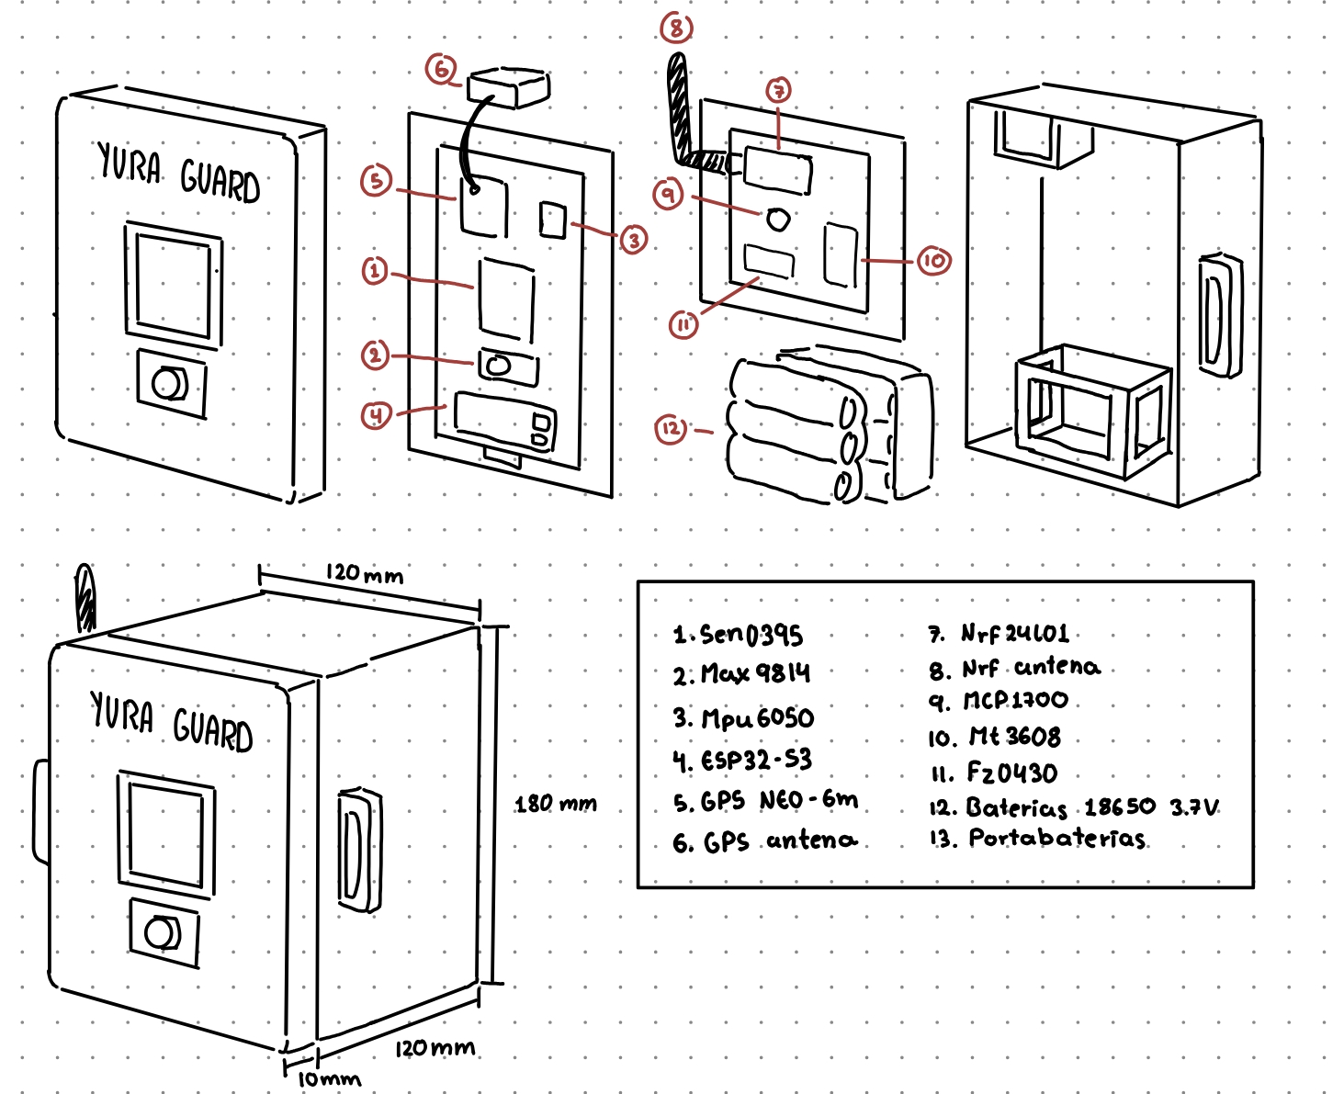
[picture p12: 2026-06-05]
Proyecto/MóduloMecánico/v2.0/Boceto/Boceto 2 original.jpeg

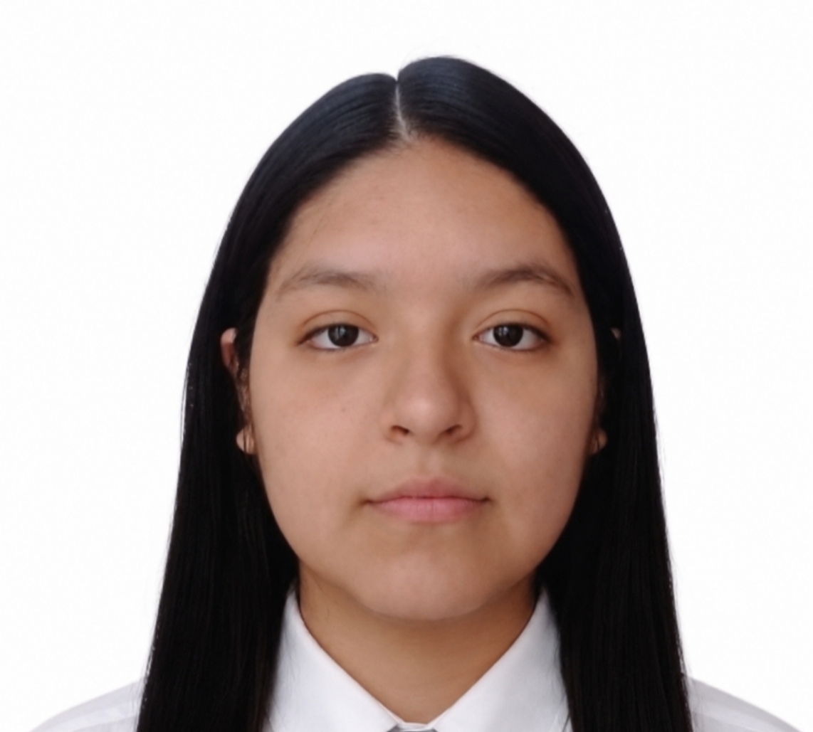
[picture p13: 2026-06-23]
Recursos/Imágenes/Martha Medina Rojas.jpeg

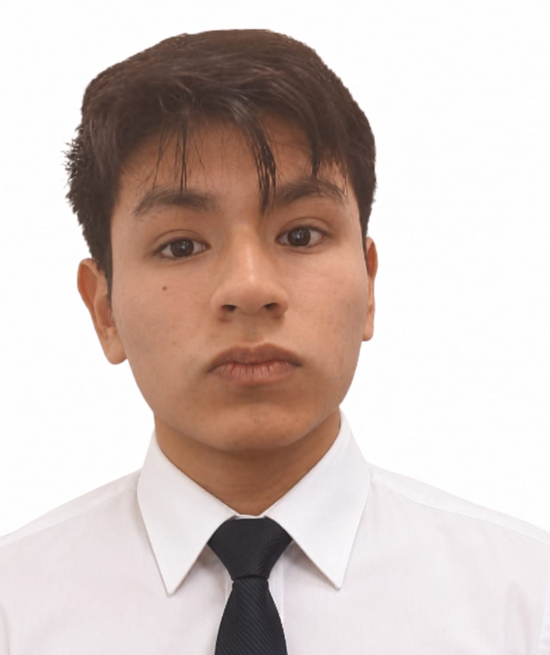
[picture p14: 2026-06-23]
Recursos/Imágenes/Anderson Bruno Sanchez.jpeg

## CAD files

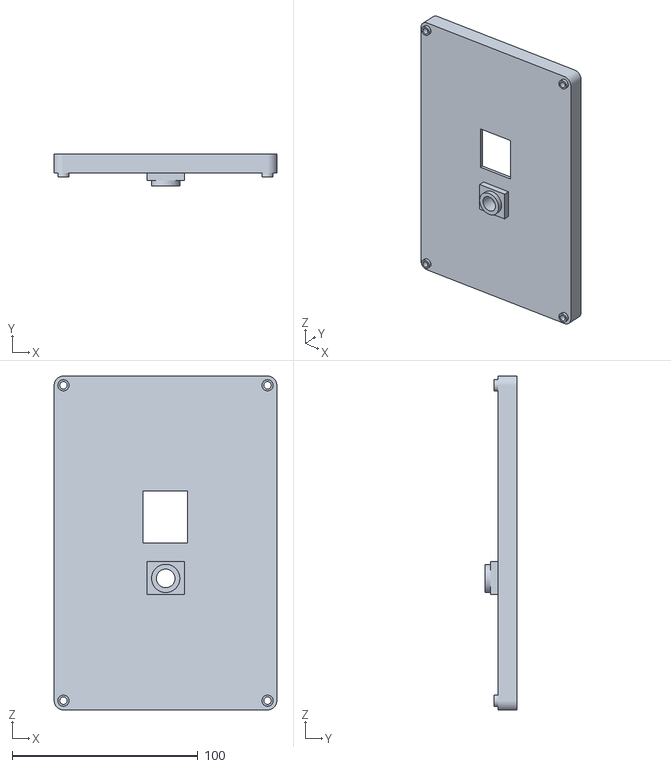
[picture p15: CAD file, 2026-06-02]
FundDiseño/Entregables/3. Entregable 3/Modelo 3d/Yura Guard_Tapa.stl
120.0 x 17.5 x 180.0

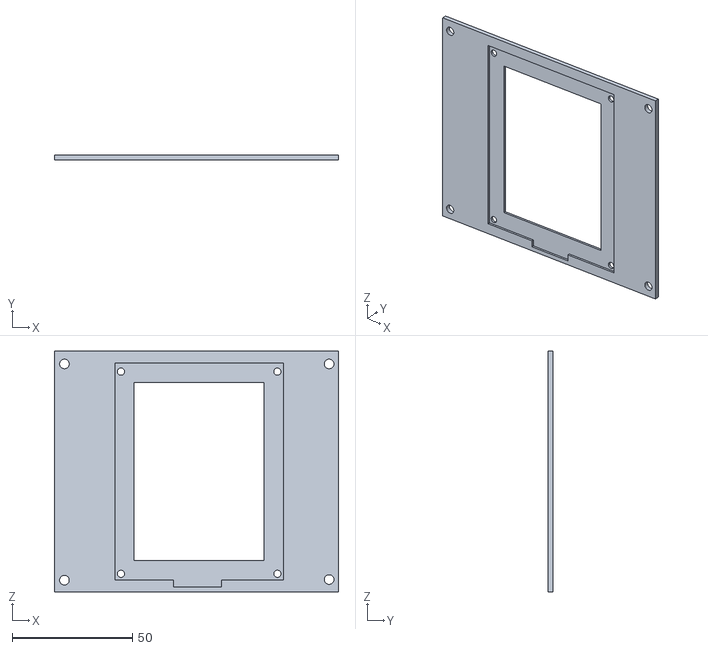
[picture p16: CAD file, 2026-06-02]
FundDiseño/Entregables/3. Entregable 3/Modelo 3d/Yura Guard_PCB2.stl
118.0 x 2.00 x 100.0

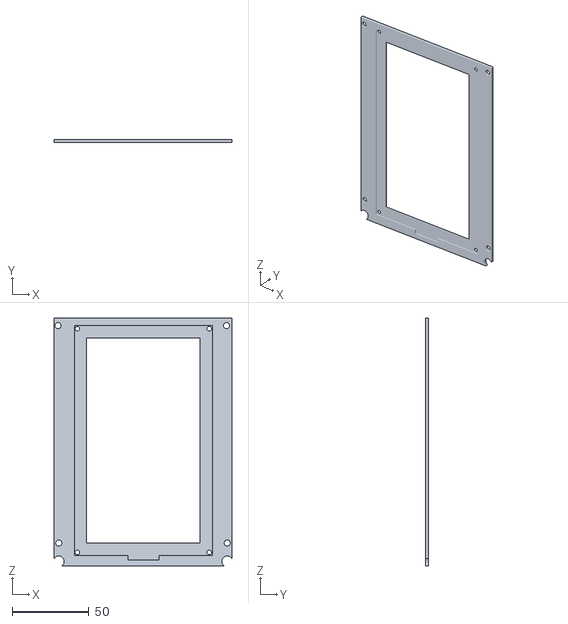
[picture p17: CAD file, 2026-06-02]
FundDiseño/Entregables/3. Entregable 3/Modelo 3d/Yura Guard_PCB1.stl
116.0 x 2.00 x 161.9

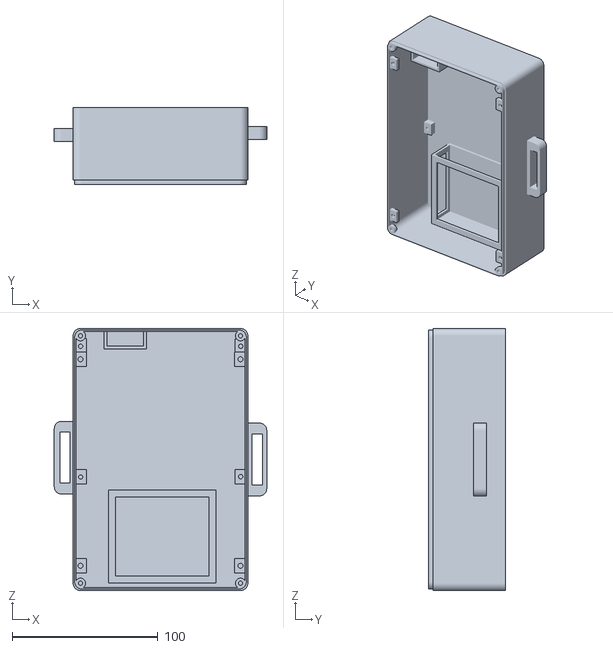
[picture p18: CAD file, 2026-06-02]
FundDiseño/Entregables/3. Entregable 3/Modelo 3d/Yura Guard_Cuerpo.stl
146.0 x 53.0 x 180.0

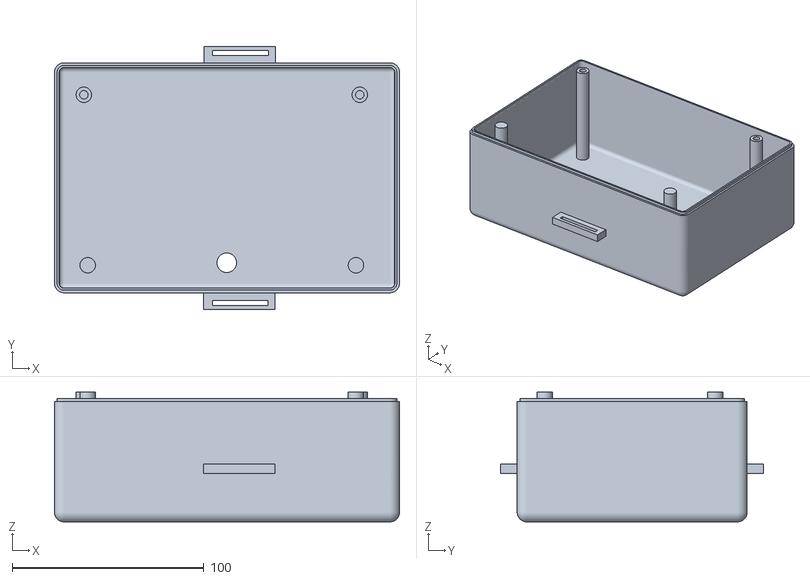
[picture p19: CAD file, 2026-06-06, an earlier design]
Proyecto/MóduloMecánico/v1.0/Onshape/partes/Parte_Cuerpo.stl
180.0 x 137.2 x 67.7

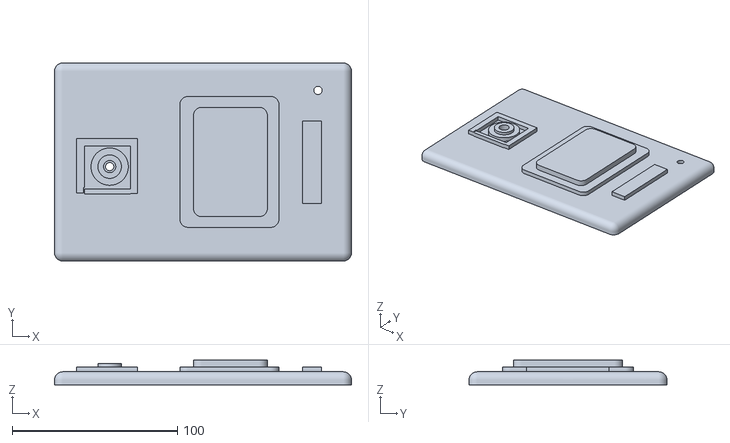
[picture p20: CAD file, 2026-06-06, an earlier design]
Proyecto/MóduloMecánico/v1.0/Onshape/partes/Parte_Tapa.stl
180.0 x 120.0 x 14.9

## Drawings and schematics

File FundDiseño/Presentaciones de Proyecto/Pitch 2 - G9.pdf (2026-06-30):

# YURAGUARD

# ‘’Escuchando el Amazonas’’

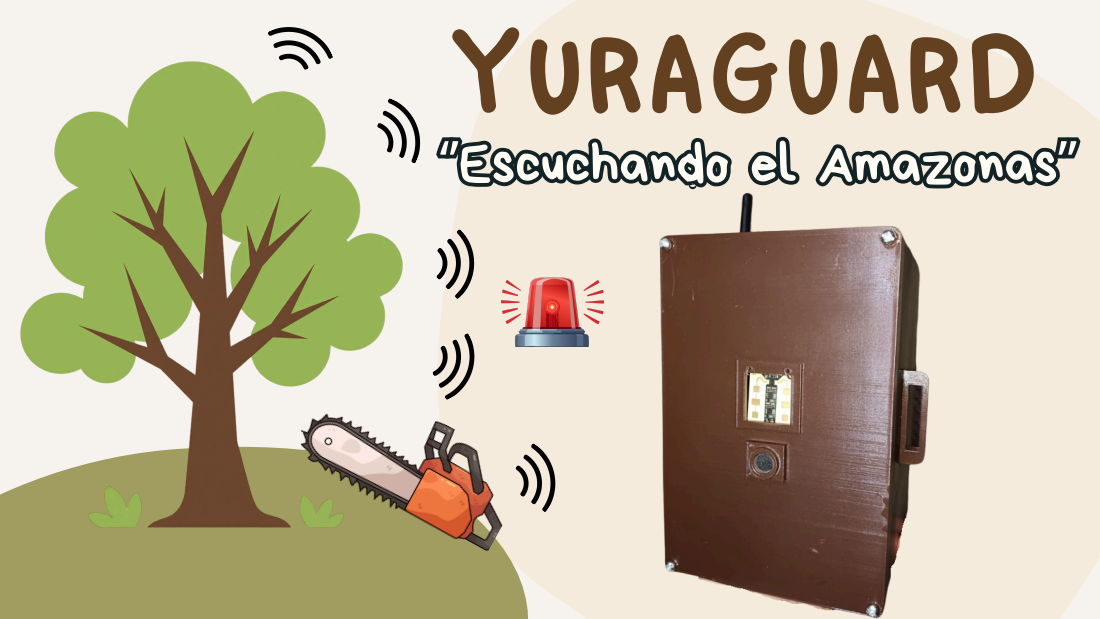
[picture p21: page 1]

# PROBLEMÁTICA

### 🌳 Amazonía

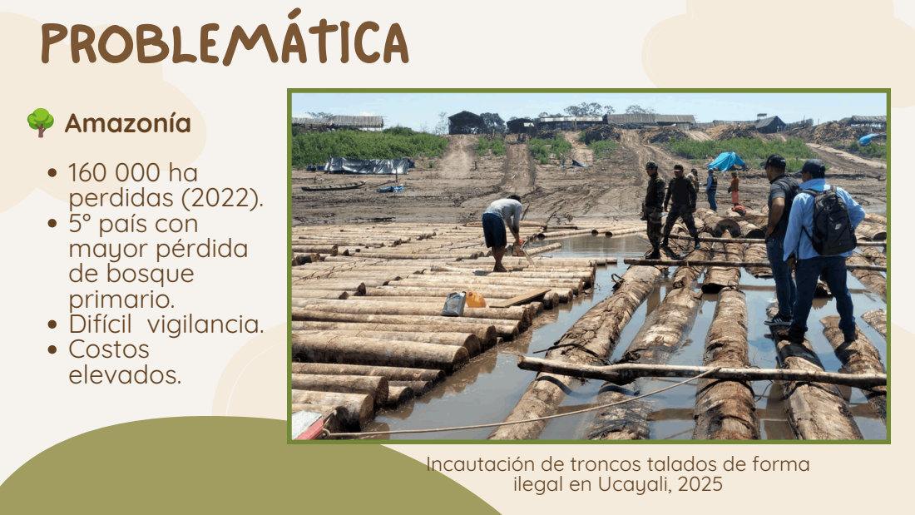
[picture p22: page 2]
160 000 ha perdidas (2022). 5° país con mayor pérdida de bosque primario. Difícil vigilancia. Costos elevados.

Incautación de troncos talados de forma

ilegal en Ucayali, 2025

# SOLUCIÓN

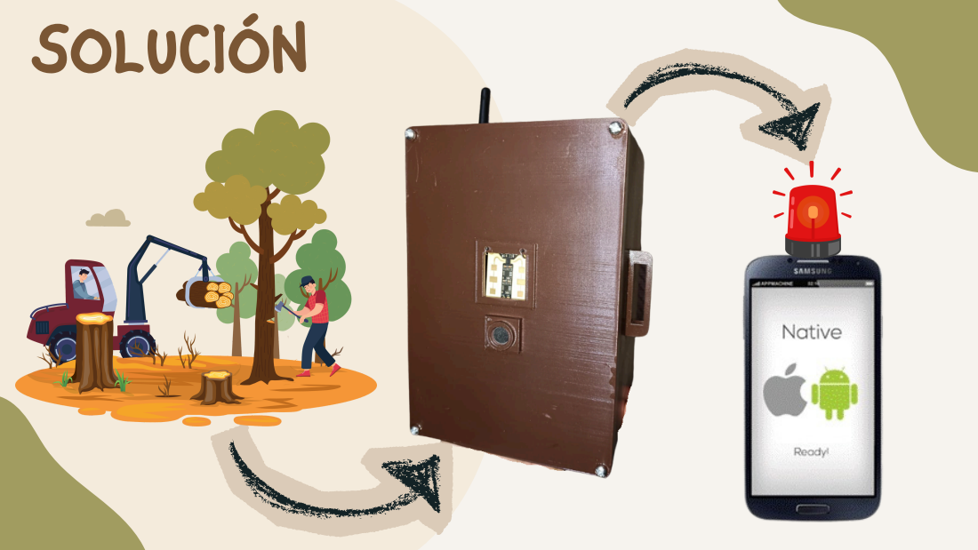
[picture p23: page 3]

# MODELO DE NEGOCIO

## CLIENTES:

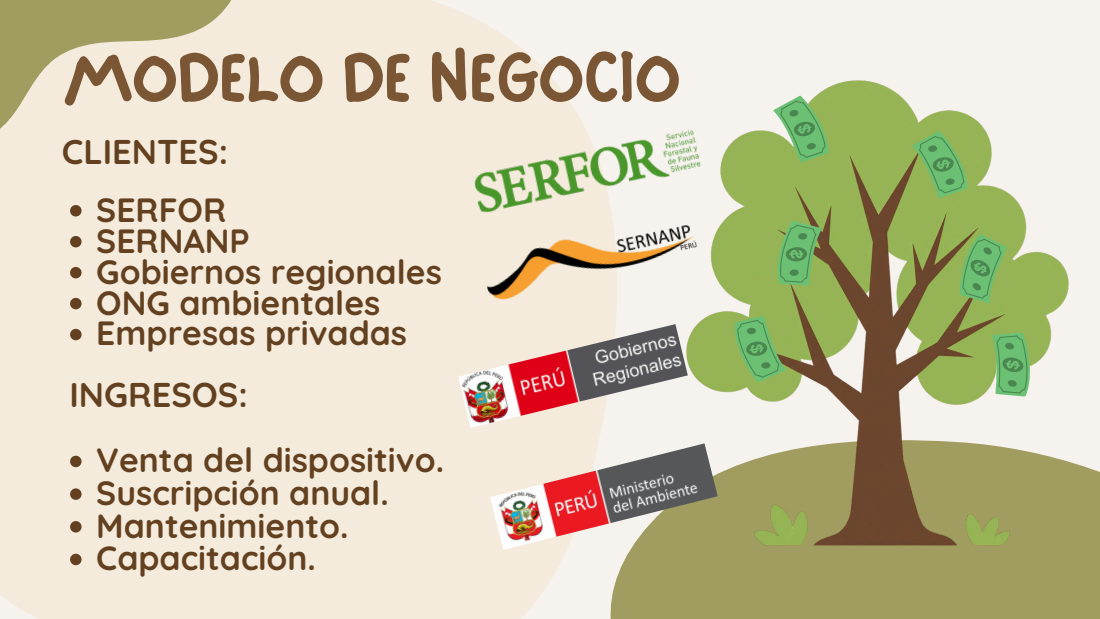
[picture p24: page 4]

SERFOR
SERNANP
Gobiernos regionales
ONG ambientales
Empresas privadas
INGRESOS:
Venta del dispositivo.
Suscripción anual.
Mantenimiento.
Capacitación.

# ESTRATEGIA

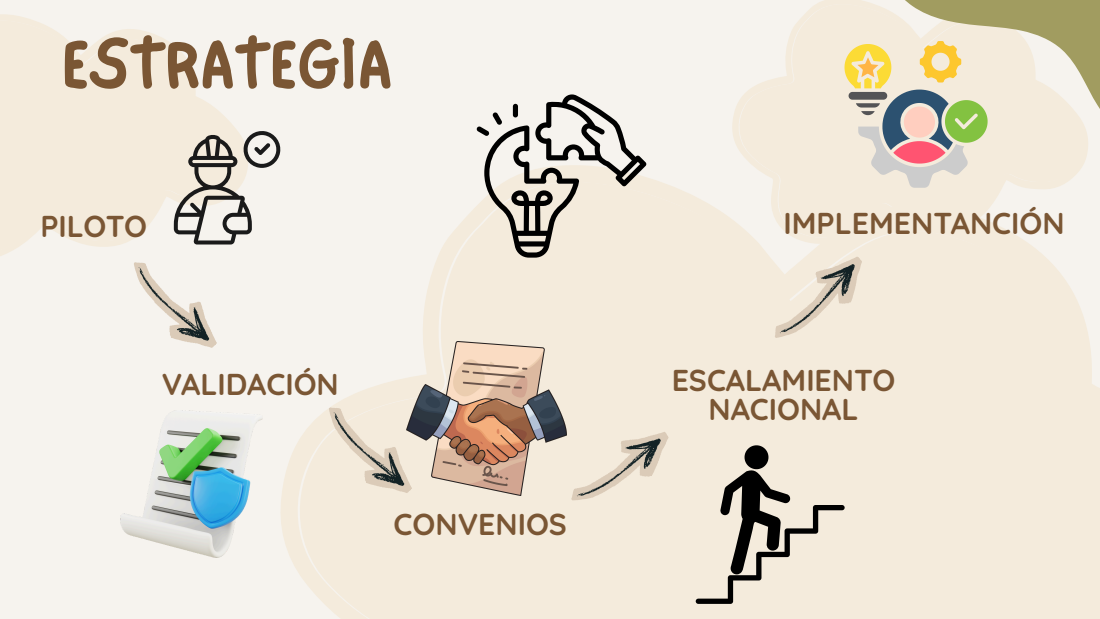
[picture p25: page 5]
ESCALAMIENTO NACIONAL; CONVENIOS; IMPLEMENTANCIÓN; PILOTO; VALIDACIÓN

# EQUIPO

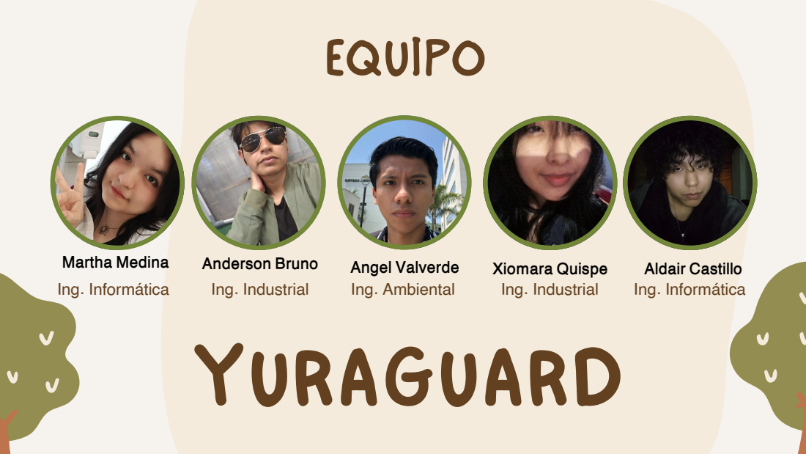
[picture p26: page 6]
Martha Medina; Anderson Bruno; Angel Valverde; Xiomara Quispe; Aldair Castillo; Ing. Informática; Ing. Industrial; Ing. Ambiental; YURAGUARD

# PEDIDO

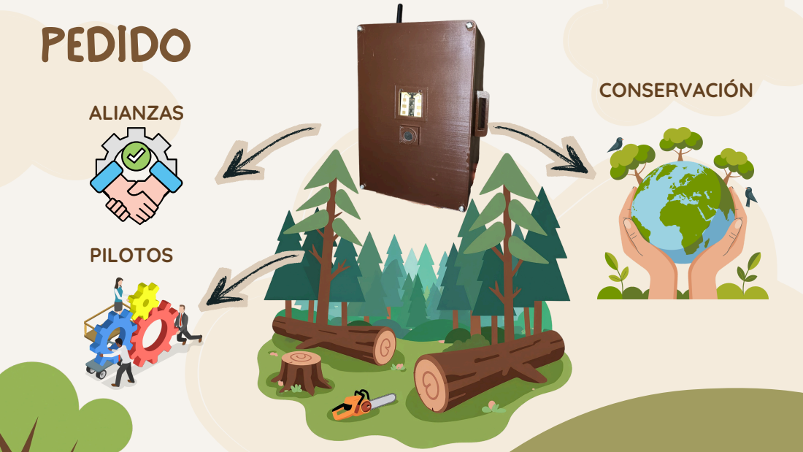
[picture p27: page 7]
ALIANZAS; PILOTOS; CONSERVACIÓN

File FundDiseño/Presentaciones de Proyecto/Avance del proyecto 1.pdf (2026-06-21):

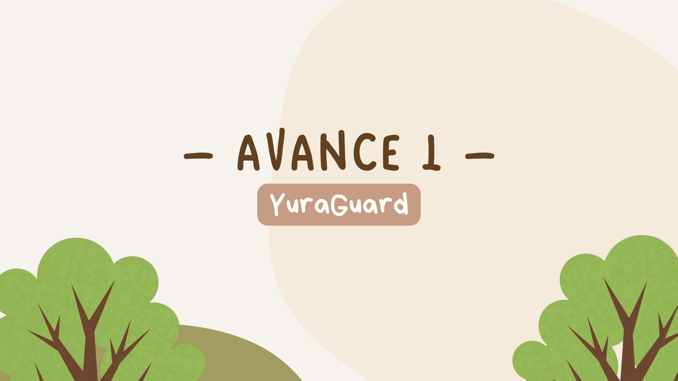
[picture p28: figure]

# EQUIPO 9

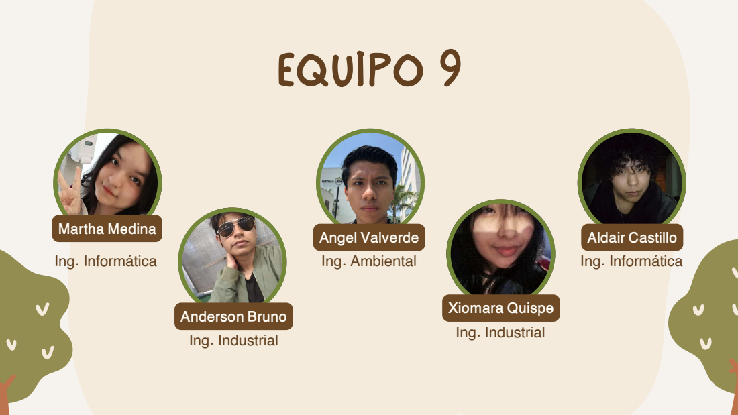
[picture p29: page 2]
Martha Medina; Anderson Bruno; Xiomara Quispe; Angel Valverde; Aldair Castillo; Ing. Informática; Ing. Industrial; Ing. Ambiental

# ODS:

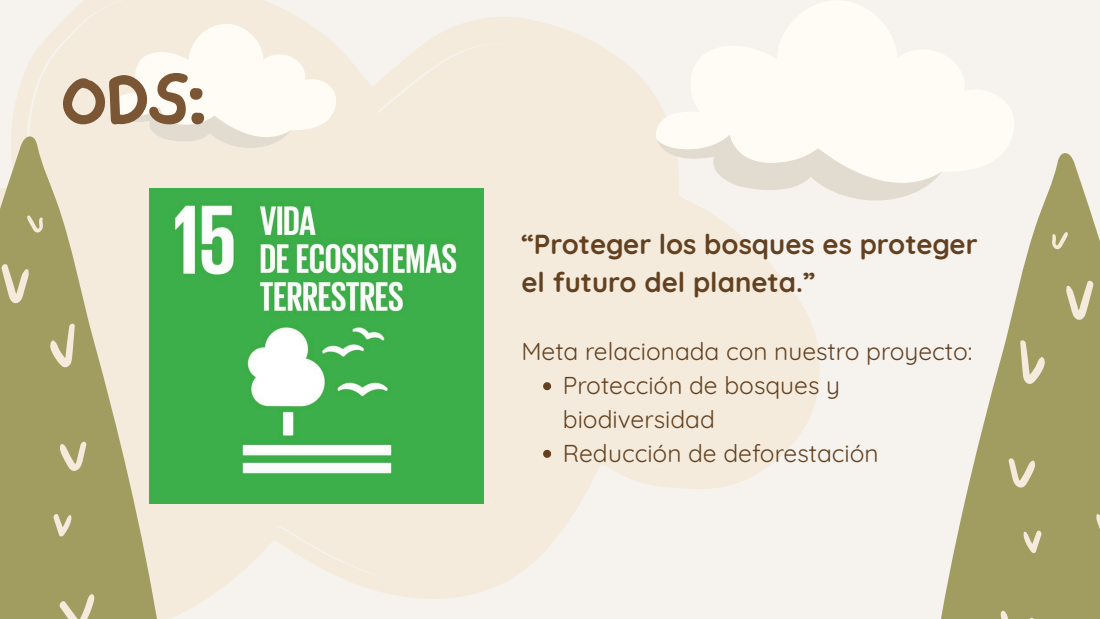
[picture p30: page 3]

“Proteger los bosques es proteger
el futuro del planeta.

Meta relacionada con nuestro proyecto:
Protección de bosques y
biodiversidad
Reducción de deforestación

# PROBLEMÁTICA

El 67% de la pérdida de
cobertura arbórea en el país
se asocia a deforestación

En el año 2022, Perú se
posicionó como el 5to país
con mayor pérdida de
bosques

En el 2024, perdió más de
190 mil

Ranking 2022 de países con mayor pérdida de bosques primarios -

Global Forest Watch

# PROBLEMÁTICA

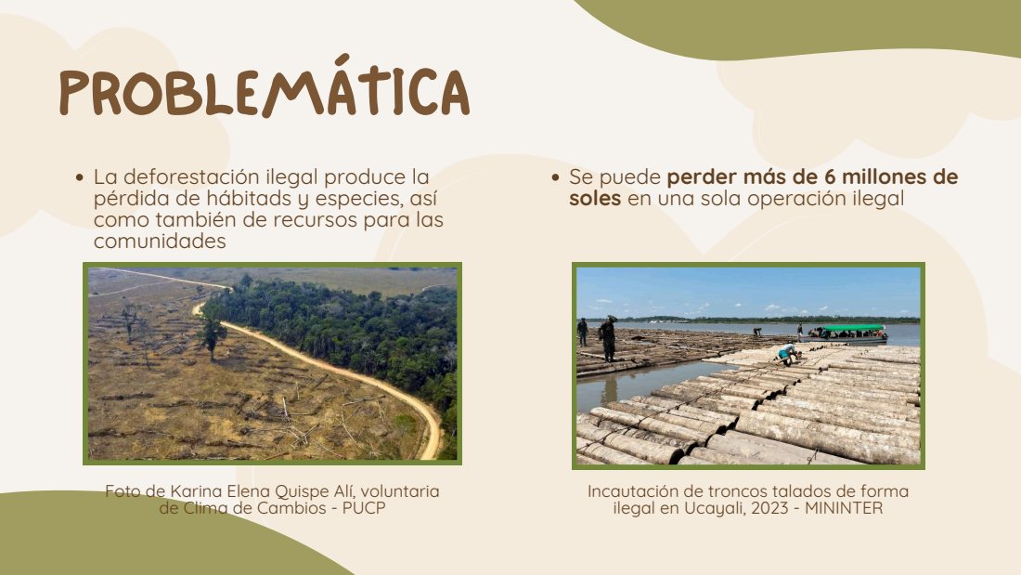
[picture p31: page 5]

La deforestación ilegal produce la
pérdida de hábitads y especies, así
como también de recursos para las
comunidades

Se puede perder más de 6 millones de
soles en una sola operación ilegal

Foto de Karina Elena Quispe Alí, voluntaria
de Clima de Cambios - PUCP

Incautación de troncos talados de forma
ilegal en Ucayali, 2023 - MININTER

# IMPACTO

Cambio climático
La deforestación libera
grandes cantidades de CO₂
Alteración del
ecosistema
Afecta la regulación del
clima

Pérdida de biodiversidad
Amenaza a un 80% de la flora y
fauna
Social y económico
Se pueden llegar a perder
importantes cantidades de
dinero y recursos

# SOLUCIONES ACTUALES:

## ADETOP V2

OSINFOR identificó más de 24 mil metros
cúbicos de madera de origen ilegal en el

Sin embargo:
Depende de la calidad de las imágenes
Cobertura institucional limitada
Detecta el daño después de ocurrido

Uso de ADETOP para la identificación de

tala ilegal - OSINFOR

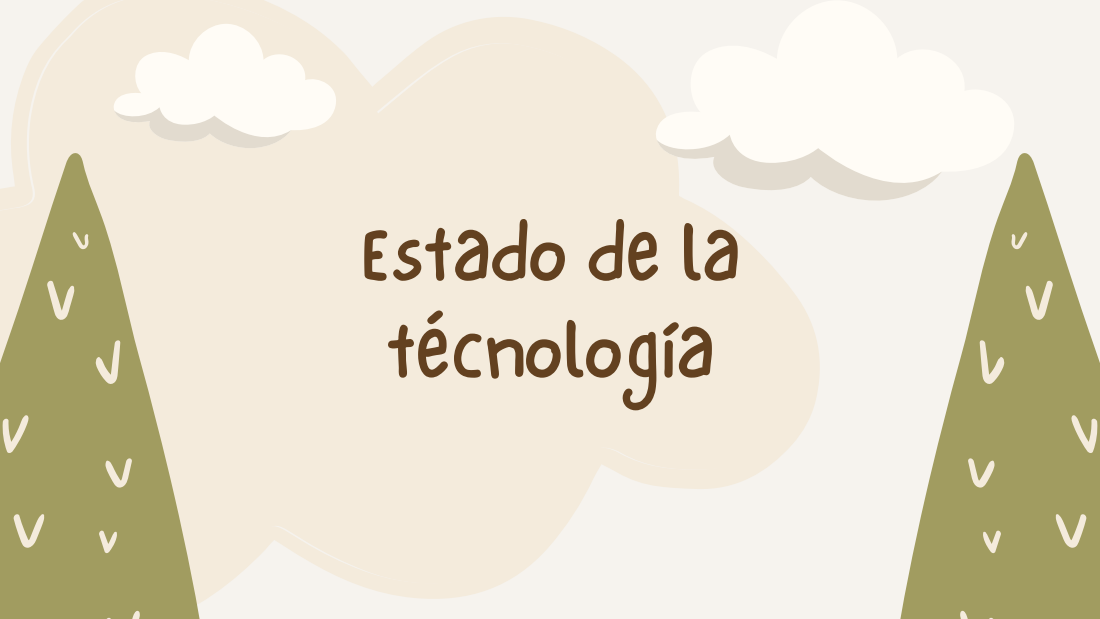
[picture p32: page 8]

Estado de la
técnología

# EXISTENTE EN EL COMERCIO


Guardian 3 (G3)
Funciona con energía solar
Capta sonidos y los envía
La plataforma envía alertas

AudioMoth
Bajo costo
Monitoreo del ambiente
Identifica patrones

Rainforest Connection. Guardian 3 [imagen en
Internet]. [citado 17 may 2026]. Disponible en:

Open Acoustic Devices. AudioMoth [imagen en
https://www.openacousticdevices.info/audiomoth

https://rfcx.org/

# PATENTES

Método, dispositivo y sistema de detección de tala ilegal basado en la diferenciación de frecuencias de audio.

Código CN102393986A

Detección acústica de tala ilegal.
Monitoreo autónomo y continuo.
Bajo costo y fácil implementación.
Geolocalización y supervisión remota.
Alternativa eficiente frente a métodos tradicionales.

Hu X, Tang Y, Mo B, Wang Y, Xiong L, Han P, Sun H. Illegal lumbering detection method, device and system based on audio frequency distinguishing. CN102393986A [Internet]. 2012 [citado 17 may 2026]. Disponible en: https://worldwide.espacenet.com/patent/search/family/045861294/publication/CN102393986A?q=CN102393986A

# PATENTES

Sistema dinámico de firmas acústicas con fusión de sensores para la tala ilegal en la selva tropical

Código US20240054154A1
Clasificación inteligente de audio ambiental. Detección temprana de anomalías sonoras. Uso de IA y redes neuronales.
Reconocimiento de patrones complejos. Sistema adaptable con entrenamiento continuo.

Wu J, Damo MA, Ain-Ul-Aisha F, Lin W, Schmarzo W. Dynamic acoustic signature system with sensor fusion for illegal logging in rainforest. US2024054154A1 [Internet]. 2024 [citado 17 may 2026]. Disponible en: https://worldwide.espacenet.com/patent/search/family/082259630/publication/US2024054154A1?q=US20240054154A1

# PATENTES

Detección de tipo de audio
Código US2025104698A1
Procesamiento de audio con IA.
Extracción de características acústicas con
modelos de aprendizaje automático
Detección temprana de anomalías.
Clasificación precisa de eventos con
algoritmos avanzados
Sistema adaptable y entrenable.

Khadloya K, Gope C, Nathan V. Audio type detection. US2025104698A1 [Internet]. 2025 [citado 17 may 2026]. Disponible en:
https://worldwide.espacenet.com/patent/search/family/067618015/publication/US2025104698A1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

# ARTÍCULOS

System Telemetry for Mobile Devices Using the GPS Neo-6M and DHT11 Modules A Case Study by IMEITeam

Cholilurrohmana, Sulistiyowati I, Wicaksono A. System telemetry for mobile devices using the GPS Neo-6M and DHT11 modules: a case study by IMEI Team. JEEMECS (Journal of Electrical Engineering, Mechatronic and Computer Science) [Internet]. 2023 [citado 17 may 2026];6(2):57-
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

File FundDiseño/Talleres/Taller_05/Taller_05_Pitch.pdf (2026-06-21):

YURAGUARD; Escuchando el Amazonas para cuidarla

¿QUÉ PASARÍA SI UN ÁRBOL
PUDIERA AVISAR QUE ESTÁ SIENDO
TALADO ANTES DE QUE SEA
DEMASIADO TARDE?

# PROBLEMÁTICA


En el año 2022, Perú ocupó el quinto
lugar a nivel mundial entre las naciones
con mayor pérdida de bosques primarios,
alcanzando aproximadamente 160,991
hectáreas deforestadas.
Según la información recopilada en 2025,
OSINFOR identificó más de 24 mil metros
cúbicos de madera de origen ilegal.

Incautación de troncos talados de forma

ilegal en Ucayali, 2023

# SOLUCIÓN

Radar mmWave 24GHz; MAX9814 Micrófono; Módulo MPU6050; Sensores

YuraGuard
Sistema de monitoreo en tiempo real que
detecta el sonido de motosierras alrededor,
la presencia humana cercana y la vibración
del mismo árbol.
Beneficios
Prevención temprana de una tala
Detección con uso de IA
Una aplicación que muestre la alerta
Integración de sensores accesibles

# MODELO DE NEGOCIO


Modelo de ingreso
Se planea vender el dispositivo a
municipalidades, comunidades nativas, ONGs
ambientales, concesiones forestales y
entidades de fiscalización
Estrategia
Desarrollo de un prototipo efectivo
Validación en entornos controlados
Creación de alianzas
Difusión por programas rurales
Ser accesible

# EQUIPO 9

Martha Medina; Anderson Bruno; Angel Valverde; Xiomara Quispe; Aldair Castillo; Ing. Informática; Ing. Industrial; Ing. Ambiental

Logros en el proyecto
Se definió una solución técnica accesible.
Se identificaron los parámetros principales.
Se realizó la lista de exigencias.

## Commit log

2026-03-17 Copiado de plantilla
    [WeatherStation_v2_Base_v2.stl, WeatherStation_v2_windmill_v4.stl]
2026-03-24 Mejora de la descripción de la ODS
    Updated the section on the Sustainable Development Goals to focus on the protection of endangered species in Peru, emphasizing the importance of monitoring and conservation efforts.
2026-03-24 Mejora de descripción ODS + imágen
    Updated team description and added details about the ODS 15 focus area, emphasizing the importance of monitoring endangered species in Peru.
2026-03-24 Pedido de modo oscuro en README
    Added a prompt for dark mode activation to README.
2026-04-14 cambio de bibliografía.md
    Updated bibliography references in README.md, adding new sources and removing outdated ones.
2026-04-14 Mejora de la problemática y la solución en README
    Updated the description of the proposed technological solution for detecting Desmodus rotundus, enhancing details on its functionality and ecological considerations.
2026-04-14 Agregación de imágenes
    Updated figure captions and added new content about a proposed technological solution to monitor and deter Desmodus rotundus in livestock areas.
2026-04-14 Arreglos decorativos y fecha de primera fuente
    Updated bibliographic references with new entries and corrected dates.
2026-04-14 separación de patente y bibliografía
2026-04-28 Update description of the monitoring device solution
2026-05-05 Add files via upload
    Avance de Proyecto 1
2026-05-18 Update README with device description and sensors
2026-05-19 Create Angel Valverde
2026-05-19 Update Angel Valverde
2026-05-19 Add files via upload
    CERTIFICADO - SEMANA 10 - ANGEL VALVERDE
2026-06-02 Add link to Onshape assembly document
2026-06-16 Add Arduino code and app design for Taller 14
    Added Arduino code for Bluetooth-controlled servo motor and app design details.
2026-06-21 Add requirements list to Taller_07.md
    Added a requirements list for the prototype workshop.
2026-06-21 Document servomotor control with ESP32 and Bluetooth
    Added detailed documentation for controlling a servomotor with ESP32 via Bluetooth, including code examples and explanations.
2026-06-23 Create Tesis de apoyo.md
2026-07-01 Create Programa_principal.md for YuraGuard device
    Added main program for YuraGuard device with sensor integration and data transmission.
